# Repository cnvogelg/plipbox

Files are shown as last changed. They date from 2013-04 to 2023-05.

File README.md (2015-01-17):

plipbox
=======

plipbox is an Arduino-based device that allows to connect low-end classic
Amigas via Ethernet to your local network. It bridges IP traffic received
via PLIP on the parallel port of the Amiga to the Ethernet port attached
to the Arduino.

Copyright (C) 2012-2015 Christian Vogelgsang <chris@vogelgsang.org>

Released under the GNU Public License V2 (see COPYING for details)

Introduction
------------

With the [plip2slip][1] project I already presented a device that uses a cheap
AVR 8 bit microcontroller (as found on the popular Arduino boards) to bridge
network traffic from the Amiga's parallel port (with the [MagPLIP][2] protocoll)
to another machine via a fast serial link.

plipbox extends the plip2slip project and replaces the serial link for IP traffic
with an on-board Ethernet port. This allows you to connect your Amiga directly
to your local network without any other machine assisting.

With the on-board Ethernet port the plipbox HW is more complex than the plip2slip
HW, but I tried to use common and easy available HW modules to simplify the
recreation of this device. This allows even novice users to build their own
plipbox. (See the hardware document for details).

The firmware for plipbox is open-source and hosted on [GitHub][3].
Clone this repository if you want to build the firmware yourself or if you
want to play around with it. 

[1]: http://lallafa.de/blog/amiga-projects/plip2slip/
[2]: http://aminet.net/package/comm/net/magPLIP38.1
[3]: https://github.com/cnvogelg/plipbox

Download Releases
-----------------

See my [plipbox blog page][4] for downloads of the current release archives.
These archives contain pre-built firmware and Amiga driver binaries in addtion
to the source code here.

[4]: http://lallafa.de/blog/amiga-projects/plipbox/

Documentation
-------------

 - [Change Log](ChangeLog.md): Changes in the releases
 - [Introduction](doc/src/intro.md): Introduction on plipbox
 - [Benchmarks](doc/src/benchmark.md): Performance measurements
 - [Hardware](doc/src/hardware.md): How to build the device hardware
 - [Firmware](doc/src/firmware.md): How to setup the firmware
 - [Amiga Setup](doc/src/amiga.md): How to setup plipbox.device on your Amiga
 - [Python Emulator](doc/src/python.md): A plipbox emulator if you run your Amiga in FS-UAE

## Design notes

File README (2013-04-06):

plipbox
=======

plipbox is an Arduino-based device that allows to connect low-end classic
Amigas via Ethernet to your local network. It bridges IP traffic received
via PLIP on the parallel port of the Amiga to the Ethernet port attached
to the Arduino.

Copyright (C) 2012 Christian Vogelgsang <chris@vogelgsang.org>

Released under the GNU Public License V2 (see COPYING for details)

Introduction
------------

With the plip2slip[1] project I already presented a device that uses a cheap
AVR 8 bit microcontroller (as found on the popular Arduino boards) to bridge
network traffic from the Amiga's parallel port (with the MagPLIP[2] protocoll)
to another machine via a fast serial link.

plipbox extends the plip2slip project and replaces the serial link for IP traffic
with an on-board Ethernet port. This allows you to connect your Amiga directly
to your local network without any other machine assisting.

With the on-board Ethernet port the plipbox HW is more complex than the plip2slip
HW, but I tried to use common and easy available HW modules to simplify the
recreation of this device. This allows even novice users to build their own
plipbox. (See the hardware document for details).

The firmware for plipbox is open-source and hosted on GitHub [3].
Clone this repository if you want to build the firmware yourself or if you
want to play around with it. 

Currently, no official firmware release is available but I will post
development snapshots to the GitHub download section so you can already
play with the device.

[1] http://lallafa.de/blog/amiga-projects/plip2slip/
[2] http://aminet.net/package/comm/net/magPLIP38.1
[3] https://github.com/cnvogelg/plipbox

plipbox Documentation
---------------------

 doc/hardware.txt               How to build the device hardware
 doc/terminal.txt               How to setup a serial terminal for command mode
 doc/amiga.txt                  How to install the AMIGA network module

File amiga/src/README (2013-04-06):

the plipbox source is heavily based on the magPLIP driver found on aminet.net:

http://aminet.net/package/comm/net/magPLIP38.1

magPLIP - SANA II compliant PLIP device driver for AmiTCP/IP, Envoy,
	    AS225 and other networking packages

  (C) Copyright 1993-1994 Oliver Wagner, Michael Balzer
  (C) Copyright 1995 Jan Kratochvil & Martin Mares
  (C) Copyright 1995-1996 Marius Groeger
      All Rights Reserved.

  Changes have been made by Stéphane Zermatten to the driver to connect
  a LinuxBox to an Amiga via a LapLing cable, based on the release 37.8.

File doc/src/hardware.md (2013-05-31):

plipbox: Hardware
=================

1. Arduino (2009) and Nano
--------------------------

The firmware was implemented on a prototype build with an Arduino 2009 board
and an ATmega328 running at 16 MHz. The final (production) version of plipbox
was build with an Arduino Nano v3 board.

You can build either version but I suggest to favor the Nano version as it is
more compact. Instead of an original Arduino board you can also use one of the
many Arduino clones if the ROM size is sufficient (32K here), the AVR chip
matches and enough I/O pins are available. Also a new Arduino Uno is a working
alternative to the 2009 version .

Setting up the missing parts for your plipbox isn't that hard:
All you need is to by some extra components and wire them together.

### 1.1 Network with ENC28J60 Chip

The essential addition to your Arduino board is a network shield or network
expansion card. Please note, that you need a network card with a *ENC28J60* chip
from Microchip. Cards using a *WizNet* chip will *NOT* work! (e.g. The Arduino
Ethernet Shield)

I used the [ENC28J60 Ethernet Module][1] from iteadstudio for the Arduino 2009
prototype. The plibpox nano version uses an [Ethernet Shield for Arduino Nano
UNO][3] purchased on ebay.

*Please note*: If you use an Ethernet shield then make sure that the shield
does not require pins that are already used for the Amiga cable (see below).
E.g. the *ENC28J60 Ethernet Shield* from iteadstudio will not work as
it uses some `DIGITAL` pins for extra functions like an SD card.

The wiring of the Ethernet module is as follows:

        ENC28J60 Ethernet Module     Function           Arduino
        ------------------------     -----------------  ----------------- 
          GND                         GND               GND
          SS                          Slave Select      DIGITAL 10 (PB2)
          MOSI                        Slave In Data     DIGITAL 11 (PB3)
          MISO                        Slave Out Data    DIGITAL 12 (PB4)
          SCK                         SPI Clock         DIGITAL 13 (PB5)
          VCC                         +3.3V Supply      (see Note)
    
*Note*: The Ethernet module needs a 3.3V supply while your Arduino 2009 needs
to run on +5V. Although the Arduiono already provides a +3.3V power source on a
pin, it will be too weak to feed the Ethernet chip. I opted to use a 5V to 3.3V
regulator to supply the ethernet module. You can use a ready-made 3.3V
regulator board if you don't want to build it yourself. See for example at
[Sparkfun][2]. The plipbox nano version does need no extra power converter. It
is already shipped with the Ethener Nano shield.

[1]: www.iteadstudio.com
[2]: www.sparkfun.com
[3]: http://www.ebay.de/itm/Ethernet-Shield-for-Arduino-Nano-UNO-R3-work-as-ENC28J60-RJ45-Webserver-/170972854883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

### 1.2 Amiga Parallel Port Cable or Adapter

You need to build a cable from the Amiga Parallel Port (DB 25 male) to the
Arduino. Try to use only a short wire length otherwise signal quality will
suffer. Up to 10 cm are suitable lengths.

The plipbox nano uses a slightly different pin out compared to the original
Arduino 2009 prototype. This change was necessary as the nano shield uses
DIGITAL 2 as (unused) IRQ line from the ENC28J60 chip. Therefore the /STROBE
signal was moved to PD3 and SELECT there moved o PB1. /STROBE needs PD3 as
the firmware tracks external INTs for this signal.

       Amiga Parallel Port         Function          Arduino          Nano
       -------------------         ----------------  ---------------  ---------------
          17 ... 22                GND               GND Pin          <- same
          1                        /STROBE           DIGITAL 2 (PD2)  DIGITAL 3 (PD3)
          13                       SELECT            DIGITAL 3 (PD3)  DIGITAL 9 (PB1)
          11                       BUSY              DIGITAL 4 (PD4)  <- same
          12                       POUT              DIGITAL 5 (PD5)  <- same
          8                        DATA 6            DIGITAL 6 (PD6)  <- same
          9                        DATA 7            DIGITAL 7 (PD7)  <- same
          10                       /ACK              DIGITAL 8 (PB0)  <- same
          2 ... 7                  DATA 0 ... 5      ANALOG 0 ... 5   <- same
                                                     (PC0 ... PC5)

#### plipbox nano Adapter Board

For the plipbox nano it is advisable to build a small base circuit board with a
parallel port connector directly soldered and two pin headers for the Ethernet
Nano shield. So you can create a very compact design that fits directly in the
parallel port of your Amiga.

I already ship a schematic and layout for a single layer PCB that provides such
a base board:

  * [Schematic](/hardware/nano_adapter/nano_adapter_sch.pdf)
  * [Board Layout](/hardware/nano_adapter/nano_adapter_brd.pdf)

### 1.3 Serial Port for Terminal Access

The plipbox device can be configured and debugged via the serial console available
on all Arduino devices. Usually you don't need extra HW to access this serial 
port.

A virtual serial port is often available via the USB connection.

Alternatively, you can connect your plip box serial port directly to your Amiga 
and then use an Amiga terminal program to control the device. In this case you
need to connect the TxD, RxD and GND wires from your Arduino to a RS232 level
converter and then to your Amiga. The level converter is essential, as the Amiga
uses +/-12V signals and the Arduino 0/5V. _NEVER_ connect your Amiga directly!

2. Pollin.de AVR-NET-IO Board
-----------------------------

The german online shop [Pollin][1] offers with the [AVR Net IO][2a] a low cost
ATmega32 board (either as a kit for 20 EUR or [already assembled][2b] for
around 30 EUR) that is suitable for the plipbox project. It already contains
the ENC 28j60 ethernet controller chip and a DB 25 connector that is already
suitable to connect the Amiga. The only thing missing in this setup for plibox
is a small wire!

[1]: http://www.pollin.de
[2a]: http://www.pollin.de/shop/dt/MTQ5OTgxOTk-/Bausaetze_Module/Bausaetze/Bausatz_AVR_NET_IO.html
[2b]: http://www.pollin.de/shop/dt/NjI5OTgxOTk-/Bausaetze_Module/Bausaetze/AVR_NET_IO_Fertigmodul.html
    
### 2.1 Add Strobe Wire

You need to add a wire from Pin 1 of the DB 25 Connector (J5) to Pin 16 on the 
ATmega (IC5):

        DB25 / J5 Pin 1 <-------------> ATmega32 / Pin 16 (PD2) 

If its difficult for you to find the ATmega pin then you can also use Pin 1 of 
the EXT connector:

        DB25 / J5 Pin 1 <-------------> EXT Conenctor / Pin 1

### 2.2 Modify Power-Supply (optional!)

If you build the board yourself you might want to replace the 9V power supply
required with a 5V regulated power supply (e.g. USB charger). In this
[mikrokontroller.net Forum Thread][mod] you find a picture with the required
adjustments for this mod:

  - Remove D1, D4
  - Replace D2, D5 with a wire
  - Remove IC1 and connect pin 1 and 3 of IC1 with a wire

Then you can use a +5V regulated power supply on J1. 
Please watch the polarity now:

(-) Minus is next to the ethernet connector

[mod]: http://www.mikrocontroller.net/articles/AVR_Net-IO_Bausatz_von_Pollin

----
That's it! All you need to construct your own plipbox HW is ready!

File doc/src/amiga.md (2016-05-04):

plipbox: Amiga Driver Documentation
===================================

0. Changes
----------

* 2011-08-05  _38.1a_  plip2slip support
* 2012-06-03  _38.1b_  plipbox support
* 2013-04-06  _0.3_    introduced own plipbox.device ethernet device
* 2013-05-19  _0.3_    converted to markdown. added more stacks
* 2015-01-11  _0.6_    adapted to new file names

1. Supported Network Stacks
---------------------------

The following network stacks have been successfully tested with plipbox:

* AmiTCP 3.0b2
* Genesis (OS3.9)
* MiamiDX (from [Classic Workbench][cwb])
* [Roadshow 1.11][rs]

[rs]: http://roadshow.apc-tcp.de/index-de.php
[cwb]: http://classicwb.abime.net

2. Setup Hints
--------------

### 2.1 Common Setup

 - All network stacks expect the plipbox device driver in `devs:networks` on
   your system volume. So copy this file first before proceeding.

 - Copy `plipbox.device` from this release in the `amiga/bin` directory to your
   Amiga installation. Select the suitable m680x0 version for your hardware
   platform and copy the plipbox.device file without the `RELEASE_000` or
   `RELEASE_020` extension:

        copy plipbox.device_RELEASE_000 devs:networks/plipbox.device

### 2.2 AmiTCP with Network Boot Disk

 - For a very simple setup you can use the [Network Boot Disk for Amiga][nwbd]
   and start with this one. You have to modify the vanilla disk as it does
   not contain the plipdox drivers, yet.

#### Initial Setup

 - Insert this disk into your favorite Amiga emulator and perform the following
   steps to prepare the disk:
 - Initial boot enters setup of the disk. Follow steps to install but cancel
   the selection of a network driver as we will add the plipbox driver later.
 - Use the setup to configure your IP, netmask, gateway, and DNS server.
 - Finally reboot to finish setup.

#### Add plipbox Driver

 - Copy `plipbox.device` on the disk to `devs:networks` (see section 2.1). I
   recommend to mount a host directory as a virtual harddisk and take the
   driver from there (my disk is called `shared`)

        copy shared:plipbox.device devs:networks/
 - Edit the file `AmiTCP/db/interfaces` and add a line for the plipbox:

        echo "plipbox dev=devs:networks/plipbox.device" >> df0:AmiTCP/db/interfaces
 - Edit `df0:Prefs/Env-Archive/nbddriver` (aka `EnvARC:nbddriver`) and
   set `plipbox0` as the network device:

        echo plipbox0 > df0:Prefs/Env-Archive/nbddriver
 - In `EnvARC:sana2/` directory you can place an optional configuration file
   called `plipbox.config`. For options see the plipbox documentation.
   A sample file is available in directory `amiga/src` of this release.
   Example:

        echo "NOBURST" > df0:Prefs/Env-Archive/sana2/plipbox.config
 - Now reboot to activate changes
 - Use `ifconfig plipbox0` to check the status of your network interface.
   It should be UP and RUNNING.

[nwbd]: http://jpv.wmhost.com/NetworkBootDisk/

### 2.3 Genesis

  - Genesis is very similar to the AmiTCP setup (its more or less a UI for
    AmiTCP and uses its core for the network stuff)
  - Copy the plibpox.device to your system (see section 2.1)
  - Open the `GenesisPrefs`
  - In `Interfaces` select `New`
    - In `Interface` Tab enter:
      - Enter the interface `Name: plipbox0`
      - Enter `IP Address, Gateway, Netmask` to match your local network
    - In `SANA II` Tab enter:
      - `Specify SANA II device: devs:networks/plipbox.device`
    - Confirm interface creation with `Okay`
    - In `Resolve` Tab do not forget to name your DNS servers and set your
      domain name(s)
  - Note: `dynamic` setup does not work with plipbox. You must either use static
    or an external [DHCP client][dhcp] suitable for AmiTCP/Genesis.
  - Now you can start `Genesis` and enable your new `plipbox0` interface

[dhcp]: http://aminet.net/package/comm/tcp/dhcp_amitcp

### 2.4 MiamiDX

  - Launch `MiamiDX`
  - Select `Hardware` Tab and click `New`:
    - In `Select Hardware Type` pick `Ethernet`
    - Enter a name for the hardware, e.g. `Name: plipbox`
    - Keep `Type: SANA II`
    - Pick plipbox.device: `Driver: devs:networks/plipbox.device`
    - Confirm with `Ok`
  - Select `Interfaces` Tab and click `New`:
    - Pick `Interface Type: Ethernet`
    - Pick `Interface connection: LAN`
    - Select your hardware: `plipbox`
    - You can either configure your Amiga statically or with DHCP: Select
    `static` or `dynamic` in `IP Type, Netmask Type, Gateway Type`. Enter
    your network parameters in static mode.
    - Note: multicast is not supported in plipbox. Therefore, keep
    `Multicast: disabled`.
    - Note: Configure DHCP in `TCP/IP Settings...` to fetch DNS servers, too.
  - In `Databases` Tab select Table `DNS servers` and add your static DNS
  server IPs (if you don't use dynamic DNS via DHCP)
  - Do not forget to save your settings with Amiga+S or `Menu: Settings -> Save`
  - Now you can go online with your new interface `plipbox`
  - If you use multiple plipbox devices in a single network then you have to
  set a unique MAC address for each one. Select `Hardware Tab` and double
  click your `plipbox` entry. Now select `SANA-II Parameters` and enter a
  new MAC address in the `Hardware address` field.

### 2.5 Roadshow

  - Begin with copying the plipbox device driver (see section 2.1)
  - Then you need an interface configuration file for the plipbox device.
  Simply copy a template from `Storage/NetInterface` and modify this one:

        copy sys:Storage/NetInterfaces/cnet devs:NetInterfaces/plipbox

  - Now adjust the following values in the file (use either static or DHCP section!):

        device=plipbox.device
        # -- DHCP --
        configure=dhcp
        # -- static --
        address=<your ip>
        netmask=<your mask>

  - Have a look in `devs:internet/name_resolution` to set your DNS servers and
  your domain name.
  - After a reboot the interface will be brought up automatically in the
  `User-Startup` section of Roadshow
  - For testing you can activate/de-activate the interface with:

        > addnetinterface devs:netinterfaces/plipbox
        > ... use network ...
        > netshutdown

  - To make sure that the plipbox device goes offline if you shut down the net
  you have to add the following options to your interface configuration file:

        downgoesoffline=yes

  - If you use multiple plipbox devices in a single network then you have to
  assign them unique MAC addresses. You can set the MAC address of your plipbox
  with the following option in your Roadshow device configuration file:

        hardwareaddress=1a:11:a1:a0:00:01

  - A complete device config looks like:

        device=plipbox.device
        configure=dhcp
        downgoesoffline=yes
        hardwareaddress=1a:11:a1:a0:00:01

3. plipbox.device Configuration
-------------------------------

While the plipbox.device is in general zero-config and needs no adjustement,
you can control some options via a configuration file.

The text file needs to be called:

        ENV:SANA2/plipbox.config

Store your file in the environment archive to have it available after the
next reboot, too:

        ENVARC:SANA2/plipbox.config

The following options are supported:

  - **NOBURST** (switch /S) (default: burst on)
    - Starting with version 0.6 a fast burst mode is used for parallel port
      data transfer. It is always recommended to use this mode. However, if
      you experience problems with fast transfers then you can use this
      option to fall back to the old transfer protocol. Its slower but
      more reliable.

  - **TIMEOUT** (numerical key /K/N) (default: 500 * 1000) (unit: microseconds)
    - The parallel transfer uses time outs to detect error conditions.
    - Use this value to adjust timing.

  - **NOSPECIALSTATS** (switch /S) (default: special stats on)
    - The SANA-II device tracks statistics information.
    - Use this switch to disable the extra statistics information that is
      recorded during normal operation of the device.

  - **PRIORITY** (numerical key /K/N) (default: 0) (unit: AmigaOS task prio)
    - A server task is used in the plipbox.device to handle the parallel port
      transfers.
    - Use this value to alter the scheduling priority of the send/receive
      task.

  - **BPS** (numerical key /K/N) (default: 60 * 1024 * 8) (unit: bits/second)
    - A SANA-II device reports a bitrate per second value as an indication
      for the achievable transfer speed of the network device.
    - Use this parameter to adjust the speed that is reported to the TCP/IP
      stack from the device.

  - **MTU** (numerical key /K/N) (default: 1500) (unit: bytes)
    - The maximum transfer unit is the maximum number of bytes a device can
      transfer in a single packet. By default its 1500 and exactly matches
      the MTU that Ethernet uses.
    - For the plipbox the MTU size is also the size of the parallel transfers.
    - Use this parameter to set a smaller MTU and tune the transfer rates.
    - Note that a non 1500 MTU will cause fragmentation on upper levels.

4. Build plipbox.device from Source
-----------------------------------

 - Only for advanced users! All others can use the supplied binaries!
   You really need to recompile the binaries only if you want to modify
   or enhance them.
 - I cross-compile the binaries here with vamos running the SAS C V6.58 compiler
 - Install [vamos][v] on your Mac or PC
 - Copy the following Amiga Directories either from a real machine or an emulator
   to a directory on your Mac. The directory is named `$HOME/amiga/shared`
   here but you can use another directory as well but need to adjust `AMIGA_DIR`
   in `amiga/src/makefile`!

        ~/amiga/shared:
          wb310             system root of a Workbench 3.1 HD Installation
          sc                complete installation directory of SAS C 6.58
          AmiTCP-SDK-4.3    AmiTCP SDK

   The [AmiTCP-SDK-4.3][sdk] is available on Aminet
 - Enter directory `amiga/src` of this release
 - Build on your Mac or PC shell with:

        > make dist       build release files
        > make all        build without optimization
        > make opt        build with optimization
        > make clean      remove files of current build
        > make clean_dist remove all build files

 - The resulting files can then be found in `amiga/bin`

[v]: http://lallafa.de/blog/amiga-projects/amitools/vamos/
[sdk]: http://aminet.net/package/comm/tcp/AmiTCP-SDK-4.3

EOF

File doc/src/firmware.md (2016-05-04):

plipbox: Firmware Documentation
===============================

1. Flash Firmware
-----------------

Depending on your AVR hardware and the bootloader it contains when shipped you
can either use the bootloader to flash the device (e.g. via serial) or you
have to use an AVR in-system-programmer (ISP) to flash the device without
running the bootloader.

Serial flashing is described in section 1.1 and 1.2 while ISP flashing is
found in section 1.3

Here is a quick overview of devices and their required flash methods:

  * Pollin.de AVR-NET-IO: needs ISP
  * Custom ATmega 328 boards: needs ISP
  * Arduino 2009 or Arduino Nano: has Bootloader with Serial Flash Support

### 1.1 Find plipbox Serial Port

You can connect your plipbox typically via the USB port to your Mac or PC
and this will install a "virtual" serial port. Other plipbox devices have the
serial port available on 2 pins with +5V signals. Then you need an external
USB-to-Serial device to convert the serial signals to a virtual serial device.

The virtual serial port is called differently depending on your OS:

 * Macs: `/dev/cu.usbserial-<serial>`
 * Linux: `/dev/ttyUSB<num>`
 * Windows: `COM1 ... COMx`

You can find out the port associated with your plipbox by looking at the
registered devices before and after attaching the device.

### 1.2 Flashing with Serial Link

Some AVR devices like the Arduino-based ones allow you to flash the firmware
via the (virtual) serial link.

First select correct firmware file for flashing. The firmware used for the
Arduino 2009 prototype is called `*-ardiuno-*.hex` and the firmware for the
plipbox nano production version is called `*-nano-*.hex`. Choose the version
matching your hardware. Both have the same features but use a slightly
different pinout for accessing the Amiga's parallel port.

For flashing the firmware you need a flash tool on your Mac/PC that talks via
this serial port. I use [avrdude][ad] here. It is available on all platforms and
a command line tools.

[ad]: http://www.nongnu.org/avrdude/

Now open a shell/terminal/cmd.exe on your OS and call the firmware tool with:

        > avrdude -p m328p -P <your_serial_port> -b 57600 -c arduino -U flash:w:plipbox-0.x-57600-arduino-atmega328.hex

This assumes that you have the plipbox firmware file called
`plipbox-0.x-57600-arduino-atmega328.hex` in your current directory.
In the release archive you can find it in the `avr/firmware` directory.

Furthermore, replace `<your_serial_port>` with the device name of your
Ardiuno serial device found in section 1.1.

If everything works well then you will see the following output:

        avrdude: AVR device initialized and ready to accept instructions

        Reading | ################################################## | 100% 0.00s

        avrdude: Device signature = 0x1e950f
        avrdude: NOTE: FLASH memory has been specified, an erase cycle will be performed
                 To disable this feature, specify the -D option.
        avrdude: erasing chip
        avrdude: reading input file "plipbox-0.x-57600-arduino-atmega328.hex"
        avrdude: input file plipbox-0.x-57600-arduino-atmega328.hex auto detected as Intel Hex
        avrdude: writing flash (16596 bytes):

        Writing | ################################################## | 100% 4.67s

        avrdude: 16596 bytes of flash written
        avrdude: verifying flash memory against plipbox-0.x-57600-arduino-atmega328.hex:
        avrdude: load data flash data from input file plipbox-0.x-57600-arduino-atmega328.hex:
        avrdude: input file plipbox-0.x-57600-arduino-atmega328.hex auto detected as Intel Hex
        avrdude: input file plipbox-0.x-57600-arduino-atmega328.hex contains 16596 bytes
        avrdude: reading on-chip flash data:

        Reading | ################################################## | 100% 3.37s

        avrdude: verifying ...
        avrdude: 16596 bytes of flash verified

        avrdude: safemode: Fuses OK

        avrdude done.  Thank you.

Now your device is fully operational and we use the serial link to communicate
with plipbox.

### 1.3 Flashing with ISP

All AVR boards can be flashed with an In-System-Programmer (ISP) device. This
device directly programs the flash ROM. The ISP is an external tool that
is also typically connected via USB to your PC. I use the [USBasp][ua] thats
a cheap AVR ISP that is supported by avrdude and has a USB connector. You can
build one yourself or buy a [kit][uk]. You also find these devices on ebay
and amazon.

The AVR-NET-IO-Board from Pollin.de needs to be flashed via ISP and this
firmware variant:

        plipbox-<version>-57600-avrnetio-atmega32.hex

Again you can use `avrdude` to flash the firmware. The command avrdude is as
follows:

        > avrdude -p m32 -c usbasp -U flash:w:plipbox-0.1-57600-avrnetio-atmega32.hex

Please note the different flash adapter `usbasp` here and that you do not need
a serial speed now.

[ua]: http://www.fischl.de/usbasp/
[uk]: http://www.fundf.net/usbasp/

2. plipbox Configuration
------------------------

The plipbox firmware uses the serial link available on your plipbox to show you
device information and allows you to configure the device in this terminal.

Starting with version 0.3 the plipbox device is essentially a zero-config device,
i.e. you don't have to alter any parameters for typical default operation.

Nevertheless, the firmware offers options to fine tune its behaviour and provides
commands for statistics and diagnosis.

### 2.1 Setup your terminal program

On your Mac/PC you will need a terminal program to talk via the serial link.
If you haven't got a favorite one then have a look at [CoolTerm][ct] for Mac OSX
or [TeraTerm][tt] for Windows. Linux users might try [minicom][mc] or [picocom][pc].

[ct]: http://freeware.the-meiers.org/
[tt]: http://www.ayera.com/teraterm/
[mc]: http://alioth.debian.org/projects/minicom/
[pc]: http://code.google.com/p/picocom/

Run your terminal program and select the serial port of your plipbox (see
section 1.1). For the serial port select the following parameters:

  * 8 N 1 = 8 data bits, no parity, 1 stop bit
  * no hardware (RTS/CTS) hand shaking
  * no software (XON/XOFF) hand shaking

### 2.2 Entering/Leaving Command Mode

If everything went well you will see the startup message of the plipbox
firmware after a reset of the device:

        Welcome to plipbox <version> <date>
        by lallafa (http://www.lallafa.de/blog)

You see all important parameters of your device and their current values.
Below is the current status of the device starting with `eth rev` that
tells you that the firmware correctly detected your Ethernet chip.

If you press **Return** in your terminal program then the device will enter
*command mode*. This mode allows you to enter commands that the device
will execute. Its mainly used to set parameters and load/save them.

While the device is in command mode it does not handle any transfers - its
completely inactive. You have to quit command mode first to return to normal
operation.

Command mode is shown with a command prompt "> " in the beginning of a line.

If you enter **q** and **Return** you give the *quit* command to leave the
command mode and the device returns to active mode.

If you enter **?** and **Return** a help text will be displayed. It shows
you all the commands that are available.

While running in active mode you can also press keys to trigger commands.
See section 2.4 for details on those keyboard commands.

### 2.3 plipbox Commands

See this section for a complete list of all commands available.

A command usually consists of a command name and optional arguments. All
are seperated by spaces on the command line. The arguments are always numbers
and given in hexadecimal (only IP address is given in decimal). The numbers
have a fixed size of either 2 or 4 digits and are denoted as follows:

  - **nn**: byte (8 bit)
    - hex value
    - always give 2 digits.
    - Example: `af`, `00`
  - **nnnn**: word (16 bit)
    - hex value
    - always give 4 digits.
    - Example: `0010`, `ab12`
  - **nn:nn:nn:nn:nn:nn**
    - 6 bytes in hex values.
    - Example: `1a:11:af:a0:47:11`
  - **nnn.nnn.nnn.nnn**
    - 4 bytes given in decimal. always give 3 digits per byte.
    - Example: `192.168.0.42`

A command is always finished by pressing **Return**.

#### 2.3.1 Common Commands

  - **q**: Leave command mode
  - **r**: Soft reset device and restart it
  - **v**: Show plipbox firmware version

#### 2.3.2 Parameter Storage

  - **p**: Show parameters
  - **ps**: Save parameters to EEPROM
  - **pl**: Load parameters from EEPROM
  - **pr**: Reset parameters to factory defaults

#### 2.3.3 Configuration Commands

  - **m nn:nn:nn:nn:nn:nn:nn** (Mac Address)
    - Set the mac address of the plipbox device.
    - Always ensure that the firmware uses the same value as the
      plipbox.device driver!
    - Normally you don't need to alter the mac address via this parameter.
      The driver will automatically push the mac address to the firmware on
      every change.

  - **fd [nn]** (Full Duplex)
    - Toggle between Ethernet full and half duplex mode. If fd is
      set to one then full duplex mode is enabled. Note: the duplex mode can
      only be switched after a reset of the device. So set your desired value
      with this command then save the parameters with **ps** and reset the
      device with **r** to test the new setup.

  - **fc [nn]** (Flow Control)
    - Toggle the use of Ethernet flow control to limit the rate
      of incoming Ethernet packets. If the parameter is set to one then flow
      control is enabled.

#### 2.3.4 Statistics Commands

  - **sd** (Dump Statistics)
    - Dump the statistics information. The plipbox records a number of
      typical network statistics including sent packets, send bytes, transfer
      errors and so on for each direction. This command prints the currently
      accumulated values.

  - **sr** (Reset Statistics)
    - Reset the statistics counters.

#### 2.3.5 Test Commands

plipbox offers a rich set of diagnosis (or test) modes. Some of them use extra
parameters that can be configured in command mode. See section 3 for details.

  - **tl nnnn** (Test Packet Length) (4 byte hex word)
    - The number of bytes that will be transferred per packet in test mode.

  - **tt nnnn** (Test Packet Ethernet Type) (4 byte hex word)
    - The ethernet type of the packets that will be sent in test mode.

  - **ti nnn.nnn.nnn.nnn** (Test Mode IP) (IP address)
    - In PIO test mode the plipbox device has its own IP address

  - **tp nnnn** (Test Mode UDP Port) (4 byte hex word)
    - In PIO test mode the plipbox answers UDP requests on this port

  - **tm [nn]** (Toggle test submode)
    - Some test modes have a sub mode. Use this command to toggle it.

### 2.4 plipbox Key Commands

If you are in *active mode* (not command mode) then you can press some command
keys to trigger actions on the device:

#### 2.4.1 Mode Selection

  - **1** (Enter Bridge Mode)
  - **2** (Enter Bridge Test Mode)
  - **3** (Enter PIO Test Mode)
  - **4** (Enter plipbox Protocol Test Mode)

#### 2.4.2 Statistics

  - **s** (Dump Statistics)
    - Dump the current statistics.
    - Similar to **sd** command.
  - **S** (Reset Statistics)
    - Reset statistics counters.
    - Similar to **sr** command.

#### 2.4.3 Diagnosis

  - **v** (Toggle Verbose)
    - If verbose is enabled then detailed information on every transfer
      is printed
    - Please note that verbose significantly degrades the performance of
      the device and should only be used for analysis purposes.
  - **p** (Send a Packet)
  - **P** (Send a Packet silent)
    - Trigger sending a test packet
    - Works in plipbox test mode only
  - **a** (Toggle auto-send Packets)
    - If enabled it will automatically send packets continuously until
      you stop auto mode again.

## 3. plipbox Run Modes

### 3.1 Terms

The plipbox device consists of two sub parts:

  - The **parallel port** connects to the Amiga. There the plipbox
    protocol (short: pb) is talked to transfer packets from/to the Amiga
    on this interface.
  - The **PIO port** (PIO stands for packet I/O). Currently, an ethernet
    controller is the PIO device of the plipbox. The PIO port transfers
    the packets to your local network.

Overview:

        | Local Network        +------- plipbox -----+
        |                +------------+    +------------------+
        |<-------------->| PIO Port   |    | PB/Parallel Port |<------> Amiga
        |                +------------+    +------------------+
        |                      +---------------------+

### 3.2 Normal Operation: Bridge Mode

After startup plipbox enters **bridge mode**. This is the normal operation mode
of the device: Both PIO and parallel port are active and packets are received
on both ports. If a packet arrives then the packet is sent on the other port.

On your Amiga you use the `plipbox.device` and your TCP/IP stack (e.g.
`Roadshow`) to transfer your internet traffic.

Incoming PIO Traffic:

        | Local Network
        |                 +-----------+
        |---- Packets --->|  plipbox  |---- Packets ---> Amiga
        |                 +-----------+                  TCP/IP Stack
        |                PIO         PB                  + plipbox.device

Incoming PB Traffic:

        | Local Network
        |                 +-----------+
        |<--- Packets ----|  plipbox  |<--- Packets ---- Amiga
        |                 +-----------+                  TCP/IP Stack
        |                PIO         PB                  + plipbox.device

Use command key **1** (see section 2.4.1) to enable this mode.

### 3.3 UDP Roundtrip Tests

These tests allow you to test sending traffic across plipbox with a special
test setup: A PC test program called **pio_test** (see `python` directory of
the software distribution) is used to generate special UDP packets that are
sent to the plipbox. The plipbox will bridge them to the Amiga and a special
test program there will return them. The returned packets are bridged back to
the PIO port and sent back to the PC. The PC test program will then send the
next UDP packet on the next round trip. After a given number of packets the
test program stops and gives you average transfer speeds.

If something went wrong then a packet sent will not arrive in time at the
pio_test program and the test will be aborted with an error.

#### 3.3.1 Loopback with TCP/IP Stack: Bridge Mode + udp_test

The basic operation in this test mode is to use the TCP/IP Stack on the Amiga
to receive and reply the packets. The plipbox device is operated in the normal
Bridge Mode. So this setup tests all components and plipbox is run in normal
bridge mode.

UDP Packet Round Trip of Test:

      +-----------+ 1. Send UDP Pkt +---------+ 2. Bridge       +--------------+
      | PC with   |---------------->|         |---------------->| Amiga        |
      |           |                 | plipbox |                 | TCP/IP Stack |
      | pio_test  | 4. Bridge       |         | 3. Reply UDP    | pb.device    |
      | running   |<----------------|  Bridge |<----------------| +udp_test    |
      +-----------+                 +---------+                 +--------------+

Tested Components:

- local network (link PC <-> plipbox)
- plipbox Bridge Mode
- plipbox.device in normal operation
- TCP/IP Stack on Amiga

Test Setup:

- On plipbox:
    - Make sure mode is Bridge (key **1**)
- On Amiga:
    - Configure your TCP/IP with plipbox.device for normal operation
    - Bring up the plipbox network interface and retrieve assigned IP: `AmigaIP`, e.g. 192.168.2.42
- On PC:
    - Make sure you can reach the Amiga by pinging the AmigaIP

            > ping 192.168.2.42

    - Now launch the test program and give the Amiga's IP

            > python27 pio_test -a 192.168.2.42 -c 1000

    - Note: The `-c` option gives the number of test packets to be sent

#### 3.3.2 Loopback with SANA-II Device Interface

This test omits the TCP/IP stack running on the Amiga. The SANA-II device
driver is still in the loop and launched by a special test program called
**dev_test** from this release.

With the missing stack the Amiga is not able to perform networking including
ARP and UDP handling. The **Bridge Test** mode of the firmware handles ARP und
UDP now on its own and only passes the packets to the Amiga for performance
evaluation.

All test packets are still transferred across the SANA-II interface of
plipbox.device to the dev_test program.

UDP Packet Round Trip of Test:

      +-----------+ 1. Send UDP Pkt +---------+ 2. Bridge       +--------------+
      | PC with   |---------------->|         |---------------->| Amiga        |
      |           |                 | plipbox |                 |              |
      | pio_test  | 4. Bridge       |  Bridge | 3. Reply UDP    | pb.device    |
      | running   |<----------------|  Test   |<----------------| +dev_test    |
      +-----------+                 +---------+                 +--------------+

Tested Components:

- local network (link PC <-> plipbox)
- plipbox Bridge Mode
- plipbox.device in normal operation
- SANA-II API

Test Setup:

- On plipbox:
    - Enter bridge test mode (key **2**)
    - In Parameters set:
        - IP address and UDP port (`ti`, `tp`)
        - Test mode ist set to **1** (`tm`)
- On Amiga:
    - Stop your TCP/IP Stack if its still running.
    - Run **dev_test** with **-d plipbox.device**
- On PC:
    - Make sure you can reach the plipbox by its address

    > ping 192.168.2.42

    - Now launch the test program and give the plipbox's IP

    > python27 pio_test -a 192.168.2.42 -c 1000

    - Note: The `-c` option gives the number of test packets to be sent

#### 3.3.3 Internal Loopback in plipbox.device

This test mode removes the SANA-II interface API from the packet roundtrip. The
packets are still sent from the plipbox to the Amiga but now the plipbox.device
returns them internally.

UDP Packet Round Trip of Test:

      +-----------+ 1. Send UDP Pkt +---------+ 2. Bridge       +--------------+
      | PC with   |---------------->|         |---------------->| Amiga        |
      |           |                 | plipbox |                 |              |
      | pio_test  | 4. Bridge       |  Bridge | 3. Reply UDP    | pb.device    |
      | running   |<----------------|  Test   |<----------------|              |
      +-----------+                 +---------+                 +--------------+

Tested Components:

- local network (link PC <-> plipbox)
- plipbox Bridge Mode
- plipbox.device internal loopback

Test Setup:

- On plipbox:
    - Enter bridge test mode (key **2**)
    - In Parameters set:
        - IP address and UDP port (`ti`, `tp`)
        - Test mode ist set to **0** (`tm`)
- On Amiga:
    - Stop your TCP/IP Stack if its still running.
    - Run **dev_test** with **-d plipbox.device**
- On PC:
    - Make sure you can reach the plipbox by pinging its address:

    > ping 192.168.2.42

    - Now launch the test program and give the plipbox's IP

    > python27 pio_test -a 192.168.2.42 -c 1000

    - Note: The `-c` option gives the number of test packets to be sent

### 3.4 PIO Test Mode

The PIO Test Mode is an isolated transfer test for the PIO port of the plipbox.
No parallel transmission to the Amiga is involved. Only the raw transfer speed
of the PIO device (here the Ethernet) is measured.

Tested Components:

- local network (link PC <-> plipbox)
- PIO device (Ethernet port) of plipbox

Test Setup:

- On plipbox:
    - Enter PIO test mode (key **3**)
    - In Parameters set:
        - IP address and UDP port (`ti`, `tp`)
        - Test mode ist set to **0** (`tm`)
- On PC:
    - Launch the test program and give the plipbox's IP

    > python27 pio_test -a 192.168.2.42 -c 1000

    - Note: The `-c` option gives the number of test packets to be sent

### 3.5 PB Test Mode

This test mode only transfers packets between the plipbox and the Amiga. The
packet transfer is initiated by the plipbox and then retrieved and replied with
plipbox.device's internal loopback.

You need to open the plipbox.device and set it to online with a tool like
[sanautil][su] or dev_test from this release.

This mode is suitable to estimate the raw transfer speed of packet sent across
the parallel port and measures the performance of the current plipbox protocol
implementation.

Tested Components:

- plipbox protocol
- parallel port transfer speed

Test Setup:

- On Amiga:
    - Stop your TCP/IP Stsck if its still running
    - Run **dev_test -d plipbox.device** or
    - Run **sanautil -d plipbox.device online**
    - Stop with **Ctrl-C**
- On plipbox
    - Enter PB Test Mode (key **4**)
    - On serial prompt:
        - Send a single test packet (key **p** or **P**)
        - Start auto test:
            - Press key **a** to begin test
            - Press key **s** to see current statistics
            - Press key **a** again to stop test
            - Press key **s** for final stats or **S** to reset stats

[su]: http://aminet.net/package/comm/net/sanautil

### 3.6 PC Test Tools

The tools are found in the **python** sub directory of the release and you need
Python 2.7 on your system to run it.

#### pio_test

This tool is used to send UDP packets to the plipbox and measures the round
trip, i.e. the time until the packet is returned from plipbox.

        usage: pio_test [-h] [-v] [-a ADDRESS] [-p TGT_PORT] [-P SRC_PORT]
                        [-s DATA_SIZE] [-c COUNT] [-d DELAY]

        optional arguments:
          -h, --help            show this help message and exit
          -v, --verbose         be verbose
          -a ADDRESS, --address ADDRESS
                                IP address of plipbox
          -p TGT_PORT, --tgt-port TGT_PORT
                                UDP port of plipbox
          -P SRC_PORT, --src-port SRC_PORT
                                UDP port here
          -s DATA_SIZE, --data-size DATA_SIZE
                                size of test data
          -c COUNT, --count COUNT
                                number of packets
          -d DELAY, --delay DELAY
                                delay in ms

### 3.7 Amiga Test Tools

The tools are found in **amiga/bin** sub directory and compiled for different
m68k CPU variants. Like with `plipbox.device` pick the one matching your Amiga.

#### dev_test

This little tool opens the given SANA-II device and waits for any incoming packets.
All received packets are simply bounced and sent back with almost no modification:
Only source and target address and UDP port are swapped.

        dev_test -D=DEVICE/K,-U=UNIT/N/K,-M=MTU/N/K,-V=VERBOSE/S

        -D=DEVICE       SANA-II device file to be used (default: plipbox.device)
        -U=UNIT         Unit of device that will be opened (default: 0)
        -M=MTU          Maximum size of packets to be received
        -V=VERBOSE      Be more verbose

Never run this tool if your Amiga TCP/IP stack is running.

#### udp_test

This tool uses `bsdsocket.library` of your Amiga's TCP/IP stack to open a UDP socket
on the given port. Any packet that arrives on this port is simply bounced and sent
back to the sender.

        udp_test -V=VERBOSE/S,-P=PORT/K/N

        -P=PORT         UDP Port to be opened (default: 6800)
        -V=VERBOSE      Be more verbose

EOF

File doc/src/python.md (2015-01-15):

plipbox: Python Emulator
========================

1. Introduction
---------------

Recently, I had some time to spend and wanted to work on the [plipbox][pb]
project's Amiga driver. Unfortunately, I only had my MacBook Pro with me and no
Amiga or plipbox hardware.

What does a SW developer do if the real hardware is not at hand?

Yes, you write an emulator that represents the missing HW in SW on a machine
you have access to...

### Adding a Virtual Parallel Port Protocol in FS-UAE

That said, I installed all required Amiga SW in a virtual environment in
[FS-UAE][fs] on my Mac and soon I had my **plipbox.device** SANA II driver
talking with the virtual parallel port in FS-UAE. What was missing now is a
protocol that communicates the complete I/O state from FS-UAE to another
process. Then I could write a standalone application that does emulate the
plipbox firmware and plipbox.device in FS-UAE would be operational.

I defined a simple two-byte bi-directional protocol called [**vpar**][vp] that
communicates any change in the emulation of FS-UAE's Amiga parallel port to an
external process and also receives external changes for input lines from the
process and realizes them in FS-UAE's emulated parallel port.

Having a POSIX compatible system with pseudo-terminals (ptys) I devised the
link between both processes as a simple file-open interface in FS-UAE and a pty
in the plipbox emulator (Note: any other interprocess mechanism works here also
but this one was very easy to add in FS-UAE).

The setup looks like this:

        +----------+                                  +---------+
        | plipbox  |                                  | patched |
        | emulator |--(opens)--> [PTY] <--(file I/O)--| FS-UAE  |
        +----------+                                  +---------+
                    <--------- vpar protocol -------->

All required changes to FS-UAE are available in my clone of the FS-UAE
repository on [GitHub][gh] in the `chris-devel` branch.

For the plipbox emulator application I chose my favorite script language
Python. With it setting up the pty for inter-process communication and
implementing the vpar protocol peer was done in a few hours.

[pb]: http://lallafa.de/blog/amiga-projects/plipbox
[fs]: http://fs-uae.net
[vp]: https://github.com/cnvogelg/fs-uae-gles/blob/chris-devel/vpar.md
[gh]: https://github.com/cnvogelg/fs-uae-gles/tree/chris-devel

### Setting up the Network

Ok, the plipbox emulator in Python can now talk PLIP via vpar's virtual
parallel port. The next step is to add access to an Ethernet device on the
lowest frame level for our plipbox emulator.

I had a look at the [pcap][pc] library that allows injecting packets into
an existing adapter, but the Python bindings often lacked the inject feature
of the library and so I dropped this idea.

Then I found a setup using a [TAP][tt] device to easily create and receive
ethernet packets from a user space application. Combine this with a real
ethernet adapter via an interface bridge and you have access to real ethernet
with a simple TAP file I/O interface (opening `/dev/tap0`) from your
application.

The setup looks like this:

        +----------+              +---------+                +----------+
        | Real Eth |              | TAP     |                | plipbox  |
        | Adapter  |<-- Bridge -->| Adapter |<-- File I/O -->| emulator |
        +----------+              +---------+                +----------+
            en1         bridge0       tap0
            +----- OS net interfaces ----+

For the real ethernet adapter I use a second USB ethernet adapter on my Mac
that is not configured (IP: 0.0.0.0) but active (up) in Mac OS X. This way OS X
does not use it and my emulator can use it exclusively.

Creating the TAP device and building the bridge with the real adapter is done
with some sudo'ed system command right in the startup of the emulator.

Note: the TAP driver is not shipped with Mac OS X itself, but you can add it by
installing the ones from the [TUN TAP OSX][to] project.

[pc]: http://www.tcpdump.org  
[tt]: http://en.wikipedia.org/wiki/TUN/TAP
[to]: http://tuntaposx.sourceforge.net

### Putting it all together

On top of the vpar Python module I implemented the magPLIP protocol layer in
an own Python class. Now all pieces to create the plipbox were available.

The plipbox main script sets up the vpar, magplip, and ethernet with TAP and
interface bridge. In the main loop it does I/O multi-plexing with select() on
the file descriptor for the vpar PTY and for the TAP file. 

A packet arriving from TAP is filtered (i.e. multicast and unknown broadcasts
are removed) similar to the real plipbox firmware and then delivered to the
emulated Amiga via the vpar connection.

A packet incoming via PLIP is directly delivered to the local network and thus
written to the TAP file.

That's it! A working plipbox running as a Python script on my Mac... 
Similar to the firmware I added some optional debugging output to see the
packet contents and to measure the timing and latency.

2. Setup
--------

If you want to setup your own plipbox emulation you'll need the following
prerequisites. Please note that the current approach relies on PTYs, TAP and
bridge network devices and thus requires an OS supporting these cool things.
I currently tested only Mac OS X and Linux. 

### Common Setup

- On all platforms you'll need a Python 2.7 without any special packages
  installed

### Mac OS X Installation

- First install the [TUN TAP OS X driver][tt] 

- The new TAP device files need special access rights to use them. I added my
  user to group `wheel` to gain access to these files:

        # dscl . -append /groups/wheel GroupMembership $LOGNAME

- plipbox sets up the interface bridge with some ifconfig commands that require
  root privileges. The script calls **sudo** to perform these actions. You can
  adjust your `/etc/sudoers` file with `visudo` to gain access without entering
  a password each time:

        %admin  ALL=(ALL) NOPASSWD: ALL

- Make sure that the ethernet interface you want to bridge is not configured
  for IP (IPv4 address is 0.0.0.0) but enbaled (i.e. up)

[tt]: http://en.wikipedia.org/wiki/TUN/TAP

### Linux Installation

- similar to OSX setup **sudo** to call commands without password

- the Linux kernel needs TUN/TAP support with the `tun` kernel module. Modern
  Linux systems ship this module already. If this module is not installed you
  can install it with `insmod tun`. Just make sure to find the device node
  `/dev/net/tun` in your file system.

- you need the `tunctl` tool. On Debian/Ubuntu systems it is available in the
  `uml-utilities` package.
  
- you need the `brctl` ethernet bridge tool. On Debian/Ubuntu systems it is
  available in the `bridge-utils` package.

3. Usage
--------

### Running plipbox

You typically run the plipbox emulator with:

      > cd python
      > ./plipbox -e <ethernet_if>

The `-e` option is required to set the ethernet device you want to use for
bridging. On Mac OS X this interface is typically named `en*`, on Linux it is
`eth*`.

You can quit plipbox by pressing `CTRL+C`. This will shut down all resources
including TAP and bridge interface and removes the vpar PTY.

### Running FS-UAE with vpar support

When the plipbox emulator is started it will wait for the connect from FS-UAE.
So start this tool next. Make sure to use my patched 
[FS-UAE with vpar support][gh]. In your FS-UAE configuration add the following 
line to enable vpar support:

      parallel_port = raw:/tmp/vpar

The path `/tmp/vpar` is the default link path that will be created by plipbox
and points to the PTY that was opened by plipbox for vpar communication. You
can change this path with the `-l` option.

You can set the environment variable `VPAR_DEBUG=1` before running FS-UAE to
see low-level vpar debug information similar to the `-d` debug switch in the
plipbox emulator.

If you quit FS-UAE then plipbox will be notified and shut down, too.

[gh]: https://github.com/cnvogelg/fs-uae-gles/tree/chris-devel

### Plipbox options

The following **plipbox options** are available:

- **-v**: enable verbose output. Shows incoming and outgoing packets.
- **-d**: enable debug output. Show the vpar and magplip diagnose messages.
  This allows you to diagnose the low level parallel protocol.
- **-e <ifname>**: Name of ethernet device to be used for bridging.
- **-t <ifname>**: Name of TAP device that will be created for packet generation
  from virtual PLIP. 
- **-l <path>**: The link that will point to the PTY that FS-UAE with vpar
  support can connect to. 
- **-E**: disable filtering of packets arriving from Ethernet
  
EOF

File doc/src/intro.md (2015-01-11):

plipbox: Introduction
=====================

This document gives a technical introduction on how the plipbox device operates.

The plipbox device firmware implements a bridge for network packets arriving
on the parallel port of the Amiga (called PLIP) and the local Ethernet connected
to the plipbox hardware.

1. NAT device
-------------

Version 0.1 and 0.2 of plipbox implemented a NAT device between the parallel
PLIP interface and the Ethernet adapter.

A NAT device connects two distinct IP networks, i.e. both the PLIP and Ethernet
side of the plipbox have different IP networks and thus the plipbox has to 
have two addresses (one for each sub net):

                             +-----plipbox-----+
                             |          1a:11:a1:a0:47:11        
        +-------+   IP  +-----------+     +----------+ ARP/IP
        | Amiga | <---> | PLIP Port |-NAT-| Eth Port | <---> Local Network
        +-------+  p2p  +-----------+     +----------+  lan
       192.168.0.1      192.168.0.2      192.168.2.133        192.168.2.x
      magplip.device         |                 |        mask: 255.255.255.0
                             +-----plipbox-----+          gw: 192.168.2.1

In this setup you have to configure quite a lot: You have to set your Amiga IP
and the PLIP port IP in an own sub net. Additionally, you have to set your
Ethernet port IP to an address suitable for your local network. If you have a
DHCP server in your local network then the plipbox firmware can use this
protocol to automatically acquire the Ethernet port IP address and sub net mask.

On the Amiga side you have to select a point-to-point networking setup in your
TCP/IP software stack. This defines one address for the magPLIP interface
(here 192.168.0.1) and one for the PLIP Port in plipbox (here 192.168.0.2).
All packets sent from the Amiga will arrive at the gateway on the PLIP Port.

Now NAT takes place and the sender addresses are replaced in all IP packets
before sending them to the Ethernet: A packet originating from the Amiga
(192.168.0.1) is sent with the Eth Port as sender (192.168.2.133) to the
local network.

If a reply IP packet arrives at the plipbox's Eth Port then NAT is reversed
and replaces the destination address of the Eth Port (192.168.2.133) with
the one of the Amiga (192.168.0.1). Then the packet is sent via PLIP to the
Amiga.

Note that in contrast to other NAT devices here no port remapping is done:
We NAT only a single machine (the Amiga) and we don't use our own ports locally.
This simplifies NATting a bit as not port maps need to be managed.

On the point-to-point link only IP packets are transported. All other types
especially ARP packets make no sense here as a HW address to IP mapping is not
required here. Unfortunately, some Amiga TCP/IP stacks do not support p2p links
very well and try to perform ARP here, too :/

However, ARP must be spoken on Eth Port to map local IP addresses to the
Ethernet MAC addresses. Whenever an IP packet (after NAT) is ready to be sent
out via Ethernet then we have to find out what Ethernet MAC address has the
destination. If the destination IP is on the local sub net (determined with the
netmask of the local network) then ARP is used to find the corresponding MAC.
Otherwise we ARP the gateway (gw) IP address on the local sub net and send
the packet there.

To make ARPing more performant plipbox keeps an ARP cache. This is a table
of IP to MAC address mappings that were already used on the local sub net.

The MAC address of the local ethernet adapter on the plipbox is set by the
firmware. The default firmware already ships with a pre-defined address. If
you use multiple plipboxes in one local sub net then you have to alter this
address for individual devices.

Regarding MTU size this approach actually can apply two sizes, one for each sub
net. While the Ethernet is typically set to 1500 the PLIP link is not limited
to this value and can use arbitrary ones. However, if the PLIP MTU is larger
than 1500 then the plipbox needs to fragment the packets but this is currently
not implemented.

In summary, the NAT approach of the firmware works well but needs quite a lot
of configuration. Furthermore, the NATing applied causes trouble to protocols
that use IP addresses inside the protocol. Most notably, the FTP needs to use
passive mode in this setup to work correctly.

Another cause for trouble in this setup is the NAT that is already applied in
most local home networks when reaching the Internet. E.g. a DSL router NATs all
outgoing traffic. So a double NAT is applied to all Amiga packets when they run
through plipbox, local network, and finally the Internet.

2. MAC bridge
-------------

Starting with version 0.3 plipbox the NAT approach is replaced by a MAC bridge.
This bridge is more "transparent" than NATting and should overcome the problems
associated with NAT.

The old Amiga network device (magplip.device) that offered a point-to-point
link is replaced with a new device driver (plipbox.device) that announces an
Ethernet compatible device. The TCP/IP stack on the Amiga now directly
generates Ethernet packets with a 1500 MTU and transfers them to the plipbox.
There the frame is directly (i.e. without any alteration) passed to the
Ethernet adapter and send to the local network.

Also any incoming frame on the local network is passed to the Amiga plipbox
device driver and deliverd as an Ethernet packet to the TCP/IP stack.

                               +-----plipbox-----+
        1a:11:a1:a0:47:11      |            1a:11:a1:a0:47:11        
          +-------+ ARP/IP +-----------+      +----------+ ARP/IP
          | Amiga | <----> | PLIP Port |-COPY-| Eth Port | <---> Local Network
          +-------+        +-----------+      +----------+  lan
         192.168.2.133         |                 |              192.168.2.x
        plipbox.device         |                 |        mask: 255.255.255.0
                               +-----plipbox-----+          gw: 192.168.2.1

Now the plipbox firmware is most transparent and essentially looks like an
ethernet device directly attached to the Amiga. In this setup no NAT is applied.

You now configure your Amiga's TCP/IP stack like it is directly attached to the
local network. Give yourself a static IP or use DHCP, set the local network's
net mask, and the default gateway. Also the stack now needs to do ARPing to map
the IP addresses to Ethernet MAC addresses and it manages an own ARP cache.

The plipbox firmware is now very slim and zero-config. The only essential
parameter is the MAC address of the Eth Port. It has to have the same value
as it is used in the plipbox.device driver. The address will be automatically
transferred by the driver to the firmware on startup. By default both use
the mac address 1a:11:a1:a0:47:11. 

The device driver uses the mac address to generate the correct source address
in each frame while the plipbox firmware uses the mac address to setup a HW
Ethernet filter so that the Eth Port only reports packets for this or the
broadcast address.

In summary, with the new approach the Amiga has a bit more to do (e.g. handling
ARP packets) but all problems that were observed with NAT are gone now.

EOF

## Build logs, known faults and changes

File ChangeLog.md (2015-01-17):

plipbox: ChangeLog
==================

version 0.1 (22.7.2012)
-----------------------

- initial public release
- converted plip2slip code base and added ethernet support
- introduced a NAT device in firmware that connects a point2point link from
  the Amiga with the local Ethernet
- added DHCP on Ethernet link
- initial HW support: Arduino 2009

version 0.2 (2.9.2012)
----------------------

- added HW support for AVR-NET-IO board

version 0.3 (19.5.2013)
-----------------------

- major redesign: removed NAT device and introducded MAC bridge, i.e.
  plipbox behaves like an Amiga Ethernet adapter and bridges all packets
  from there without alteration
- dropped lots of network code found in plipbox that is not needed for the
  MAC bridge
- rewrote and renamed Amiga SANA-II plipbox.device to be an Ethernet driver
- added a Python-based software emulation for the plipbox that operates with
  a patched FS-UAE Amiga emulator
- new approach makes the device zero-conf. Just attach and it works.

version 0.4 (01.6.2013)
-----------------------

- added hardware description for plipbox nano hardware
- added schematic and board design for plipbox nano base board
- added new firmware -nano for new plipbox nano pinout
- Amiga driver unchanged and stays at 0.3

version 0.5 (30.11.2013)
------------------------

- plipbox device now automatically receives its MAC address from driver
- you can change your MAC address with SANA-II command in software
  (if your TCP/IP stack supports it, e.g. Miami DX or Roadshow)
- plipbox device maps online/offline state to Ethernet module and
  disables it if devie is offline
- parallel line protocol completely rewritten to use a client server model
- added optional Ethernet full duplex support
- added optional Ethernet flow control
- improved device statistics
- added error log

version 0.6 (17.01.2015)
------------------------

 - new fast burst protocol for raw parallel transfers of up to 235 KiB/s
 - see benchmark.md for detailed performance values
 - cleaned up firmware and driver code
 - rewrote firmware to handle a full ethernet frame in SRAM
 - reduced parameters in firmware -> simplified usage
 - added new test modes to allow detailed benchmarking of all system components

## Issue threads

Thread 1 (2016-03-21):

Assistance needed connecting Strobe to EXT

Cjsnet, 2016-03-21:
Hi, you're hard to get hold of! Having tried Twitter to no avail, and finding Wordpress won't accept comments at this time, I'd be most grateful of a response here or anywhere.

I simply have 2 questions for the AVR-NET-IO:

1. Which pin is pin 1 of the EXT? A photo would be great showing the Strobe wire connected.
2. Does the AVR-NET-IO require power or will the Amiga parallel port power it?

Thanks in advance! :)

cnvogelg, 2016-03-28:
Hi,

just having a RL with 3 little ones :) So updates/comments usually take
time...

1. I just added a picture to the plipbox hardware page
2. Yes. Parallel port is not powerful enough to supply the circuit (10mA
vs. 300mA...)

Best,
Chris

Am 22.03.16 um 00:13 schrieb Cjsnet:
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

Cjsnet, 2016-03-28:
The picture at http://lallafa.de/blog/wp-content/uploads/2012/07/avrnetio_strobe.jpg is great, thank you. Sorry for asking in more than one place, I understand now about the little ones! Thank you and congratulations.

Cjsnet, 2016-04-14:
Hi again, would you please kindly offer your help with flashing firmware to the AVR-NET-IO as per my 2 questions here: http://eab.abime.net/showthread.php?p=1083815#post1083815

Replying at that thread may be best. Thank you in advance.

Patiently yours,

Cjsnet, 2016-04-28:
Please note a lot of errors with your instructions, that have led to a lot of dead ends and confusion:

A) https://github.com/cnvogelg/plipbox/blob/master/doc/src/amiga.md
2.2:
- The URL for Network Boot Disk is wrong (take care with trigger happy clipboard pasting)
- df0:s/Prefs/Env-Archive/nbddriver should be df0:Prefs... (no s/)
- "Adjust your AmiTCP:bin/startnet and rename the interface to plipbox0" makes no sense. What is "the interface". No such reference in "startnet". See http://eab.abime.net/showpost.php?p=1086435&postcount=11

B) https://github.com/cnvogelg/plipbox/blob/master/doc/src/firmware.md
- Please make it much clearer on the "Hardware" page and here, that the AVR-NET-IO *must* use ISP requiring another purchase to go that route. I lost a day of life trying to flash it via USB Serial, because you only mention that further into the document, not at the start – and most users "start" at the start, *then* work their way down.
1.3:
- URL for "USBasp" and "kit" are wrong links.

Thank you for all your work and I hope this feedback is useful so future users attempting the project don't have the same problems I did.

I look forward to your reply about "the interface" above.

cnvogelg, 2016-05-01:
Thanks for the corrections.
I updated the docs in 85a5737.

The AmiTCP section was cleaned up. Initially it contained information for both vanilla AmiTCP installs and the Network Boot Disk. Now I focus on the boot disk alone to avoid confusion.

Cjsnet, 2016-05-01:
Thank you.

1. Before "Insert this disk into your favorite Amiga emulator and perform
the following steps to prepare the disk:" you need a step, "Run the disk
once and let it configure itself". Without that step, first boot setup of
it will delete plipbox.device as an unwanted file.

2. Please clarify, where/how do I "set plipbox0." IE what does "set" mean?
Type?

Thanks again!

On Sun, May 1, 2016, 12:18 Christian Vogelgsang <notifications@github.com>
wrote:

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

Cjsnet, 2016-05-03:
Please assist at http://eab.abime.net/showpost.php?p=1087340&postcount=16
Can't get plipbox online using these instructions. Thank you!

cnvogelg, 2016-05-04:
I just patched the disk myself (last time I did this was ages ago :)) and re-wrote this section again.
Hope this helps...

Cjsnet, 2016-06-02:
Things are working great now and I finally am able to send and receive email on an A500. Quite a feat!

2 issues left:

1. The Internet seems to get disconnected after some time (20 mins+) and I have to reboot. Is there something I should be doing / some command, to keep the net alive? It feels like the AVR-NET-IO is failing. (The ethernet LED keeps flashing random patterns so data is being sent/received.)

2. If I simply power cycle the A500 at that point, user-startup fails to get AmiTCP to connect, whereas on a full power cycle of the plipbox itself, the net works perfectly on startup. Therefore, for some reason the AVR-NET-IO needs to be turned off then on every 30 mins in order to keep the net alive.

Any ideas please?

Cjsnet, 2016-11-19:
@cnvogelg RSVP to the message above.

cnvogelg, 2016-11-19:
Please record serial logs from the device from startup until the disconnect happens. Maybe we can see here whats happening.

Cjsnet, 2016-11-19:
@cnvogelg Good idea. How do I do that?

cnvogelg, 2016-11-19:
The AVR-NET-IO has a RS232 serial connector (DB9) next to the ethernet port. You need to connect your PC to this port to record the log. Typically, you'll need a null modem cable and a RS232/serial to USB converter.
Then launch a terminal program on your PC (like TeraTerm on Windows) select the COM port of the USB adapter and set 57800 Baud Rate. There you should see the welcome message of the pillbox after power on and errors if something went wrong.

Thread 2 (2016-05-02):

Is PIO test mode ping capable?

tobox, 2016-05-02:
According to the documentation in https://github.com/cnvogelg/plipbox/blob/master/doc/src/firmware.md#34-pio-test-mode the PIO test mode should answer ping requests. In my case, it did not, but UDP packets were successully replied. A quick inspection of the source code seemed to indicate that the PIO test mode does indeed only handle ARP and UDP, but no ICMP. Am I missing something or is there an error in the documentation?

Regards
Thomas

cnvogelg, 2016-05-04:
Well spotted. Ping is indeed missing in this mode. I'll correct the docs...

patrikaxelsson, 2022-12-30:
@tobox: can this issue be closed after the doc update?

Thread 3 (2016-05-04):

plipbox.device 0.6 does not work

apaul007, 2016-05-04:
Hello,
i tried the plipbox.device 0.6 with a crasbe plipbox and an AVR NETIO. Both using 0.6 firmware. No function. With the device version 0.5, both hardware is working. (Hardware left on 0.6 fw)

Regards
Andreas

cnvogelg, 2016-05-04:
The 0.6 driver uses fast burst mode on parallel by default. Thats the major change in this version.
I suspect that this mode does not work on your HW.

You can disable the burst mode in 0.6 with:
```
echo NOBURST > EnvARC:sana2/plipbox.config
```

What Amiga system are you using?
It would be very helpful to get serial output of the plipbox to have a chance for further diagnosis...

apaul007, 2016-05-04:
I tried this already but just found out plipbox.config was in wrong path. Now, with correct location: If NOBURST ist set the 0.6 device works.
My hardware is an Amiga 2000 with GVP G-force 030 @ 25 MHz and an Amiga 1200 with Blizzard 1230 IV @ 50 MHz. Both running OS 3.1

From which mode do you need debug output? I have a serial interface ready at the NETIO.

cnvogelg, 2016-05-05:
PB Test Mode is best suited to debug these kinds of problems (see section 3.5).
It only transfers packet data across the parallel port.

Start with sending single packets manually with 'p' and see if errors occur and record the output.
Then also try an automatic session with 'a' and let it run for some time. Show statistics with 's'.

apaul007, 2016-05-10:
I tried PB Test Mode with the A2000 and the AVR NETIO plipbox. Between there is a 1m parallel port cable. Amiga runs dev_test -d plipbox.device

Here is some serial output. PB Test mode, auto

cnt  bytes    err  drop rate
0000 00000000 0000 0000 0000.00 KB/s rx plipbox
0000 00000000 0000 0000 0000.00 KB/s tx
0000 00000000 0000 0000 0000.00 KB/s rx pio
0000 00000000 0000 0000 0000.00 KB/s tx
cnt  bytes    err  drop rate
0000 00000000 0000 0000 0000.00 KB/s rx plipbox
0000 00000000 0000 0000 0000.00 KB/s tx
0000 00000000 0000 0000 0000.00 KB/s rx pio
0000 00000000 0000 0000 0000.00 KB/s tx
000060.7713 [AUTO] off

single p events

000066.2320 [RX:22] ok n=1514 d=5151 v=0073.48 KB/s  +req=+0018
000066.2650 [TX:11] ok n=1514 d=5022 v=0075.36 KB/s
000067.2692 [RX:22] ok n=1514 d=5128 v=0073.81 KB/s  +req=+0018
000067.3021 [TX:11] ok n=1514 d=5016 v=0075.45 KB/s
000067.6785 [RX:22] ok n=1514 d=5101 v=0074.20 KB/s  +req=+0018
000067.7118 [TX:11] ok n=1514 d=5100 v=0074.21 KB/s
000067.8840 [RX:22] ok n=1514 d=5158 v=0073.38 KB/s  +req=+0018
000067.9170 [TX:11] ok n=1514 d=5024 v=0075.33 KB/s
000068.0804 [RX:22] ok n=1514 d=5151 v=0073.48 KB/s  +req=+0019
000068.1136 [TX:11] ok n=1514 d=5064 v=0074.74 KB/s

salocinx, 2016-11-15:
Hi - I have currently the same issue using firmware 0.6 on my A1200 with Blizzard 1230 IV, A3000D/16 and A600/ACA620. It does not work with 0.6 but fine with 0.5 if I flash the Arduino to 0.5 and using device driver 0.5. Altough, on my A3000D/A3640 and my A4000/060 it works fine with 0.6.

I am using MiamiDX10 on all machines. But the "NOBURST" flag in ENVARC:SANA2/plipbox.config has no effect at all on the machines v0.6 is not working. Do I need to place plipbox.config at another place when using MiamiDX10 instead of AmiTCP?

Thanks.

cnvogelg, 2016-11-19:
Hi,
the config file is hard-coded in plipbox.device to `ENV:SANA2/plipbox.config`.
It is read by the device itself therefore it does not matter what TCP/IP stack is used.

Lotusshaney, 2017-04-28:
Thanks, This fixed my problem on an A4000/GVP 040 WB 3.9 with pillbox v0.6 not working at all.  I had response times on a trace route of over 3000 MS !

Lotusshaney, 2017-05-05:
FYI,  I just updated my Amiga A4000 with boingbags 3&4.  One of these contains a fix for Genesis for small packet corruption.  I can now run my Plipbox without NOBURST enabled and speeds have gone from 55,000-60,000 cps to 104,000 cps using iBrowse !!!

salocinx, 2018-06-02:
> Where exactly is this "echo NOBURST > EnvARC:sana2/plipbox.config " go? The Startup-Sequence, User-Startup or what? It would be nice if there was a little more clarification.

This is an AmigaDOS command. You need to enter this line to a CLI or Shell window. It basically creates a new file called `plipbox.config` if not yet existent and does simply write "NOBURST" into that file. The plipbox driver looks up this file when started and reads out it's content and does the appropriate processing; in this case, disabling the burst-mode introduced in revision 0.6 of the plipbox driver. Please re-check if `plipbox.config` is indeed at the `EnvARC:sana2` folder. I did test this and worked always fine.

I don't have additional information on the /S switch myself; maybe somebody else?

soydemadrid, 2019-08-10:
Hi I can't get my Plipbox on A4000 with MiamiDx to work.

I've also tried the echo NOBURST > EnvARC:sana2/plipbox.config

too but it makes no difference...

DHCP isn't working, and if I use static addresses it just says it is online but anything I ping gets 100% packet loss.

I have the boingbangs already updated too.

It may be that I have a faulty parallel port as I know my serial port doesn't work.

I bought a Hypercom board so I have more serial and parallel ports which I know do work. How do I set the Plipbox to work on my Hypercom parallel ports instead of the built in default parallel port?

Thanks for any help

10MARC, 2019-12-10:
I had the same issue as Soydemadrid above - 100% the same. I had bought a Plipbox using a cheap Thinary Electronic Arduino, and I could not even flash it back to V .5 - It would not work with any version of the AVRDUDE software at all. I could use a terminal program to log into it, though.
I solved my issue by buying a higher quality Arduino right from Arduino - I still had to flash it to V .05 to get it to work. It was totally unresponsive to the "NOBURST" trick in plipbox.config - It just did not care and would never see the network. Downgraded to .05 and it came online and worked within about 5 seconds.
I tried it on an Amiga 2000 with a GVP 040 card and an A1200 with a Blizzard '40 card. If I could flash the cheap Arduino I could probably get it working, too.
Maybe there is an issue with the V .06 firmware?

salocinx, 2019-12-10:
The Chinese Arduino clones use usually the CH340 USB to Serial chip. The Atmel CPU is the same for the Chinese and original Arduino boards. Therefore you need to install the appropriate CH340 driver in order to flash these boards. [Here's a link to the CH340 driver](https://cdn.sparkfun.com/datasheets/Dev/Arduino/Other/CH340DS1.PDF).

10MARC, 2019-12-10:
@salocinx Thanks for that info - I do have those drivers - the guy who assembled the Plipbox linked them to me. Using a terminal program to get into the Arduino works 100% and I can change settings, it is just reflashing which does not work. It always reports that it cannot connect to the programmer because it is out of sync. Tried every BAUD rate known to man, and three different programs. The new Arduino board and a second one I have both reflash without much trouble - so I am pretty sure it is a funky board.
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
craziazkowboi, 2023-05-22:
I don’t know if this would work for you too, but try putting a heatsink on the ethernet board cpu.  It has worked miracles for me - A1000 with a 68030-TK2 and using Burst mode.  Never worked prior, works flawlessly now.

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

salocinx, 2023-05-22:
Some also say, that old capacitors might be the problem. Signal quality on the parallel port probably improves with new capacitors.

craziazkowboi, 2023-05-22:
Yes, yes, I also had to re-cap my Amiga 1000 before I could use the Plipbox reliably.

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

powaking, 2023-05-22:
My A1200 was professionally recapped. I will try and see if I can get a heat sink on the Ethernet cpu. I am using a pistorm32 right now. I can try with my Blizzard but doubtful if that will show any difference.

salocinx, 2023-05-22:
The ENC28J60 Ethernet controller chip indeed can get hot. As long as you can put your finger on it, it should be fine. But as craziazkowboi already mentioned, it's normally a good thing to cool it with a little heat sink. It's worth a try.

craziazkowboi, 2023-05-23:
I also switched to using USB to power my POlipbox rather than the barrel connector, I think this also helped along with the heat sink.  If that doesn’t work, I got nothin' :)

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

salocinx, 2023-05-23:
You may want to post a picture of your device. Have you installed pull-up resistors on the data and control lines?

powaking, 2023-05-23:
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

this is my plipbox. I did not build it, it was given to me as a gift. As you can see I can not use USB to power the device and must rely on the barrel connector. I don’t feel anything being warm enough to warrant a heat sink.

salocinx, 2023-05-23:
The ENC28J60 chip which is sometimes getting hot, is beneath the Arduino Nano, on the middle PCB. Can you remove the Arduino Nano (socket or soldered) ? If so, you could run the Plipbox for some time and then turn-off the Amiga and remove the Arduino Nano and check the temperature of the chip beneath.

craziazkowboi, 2023-05-23:
Before adding any heat sinks - the chip in the middle is the one to add a heat sink too.  The Nano Uno runs very cool and does not need a heat sink at all.

￼

OK…I got a bit excited and put heatsinks on everything, but the only one needed was the one in the middle, just behind the ethernet socket.

￼

Hope this helps!

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

powaking, 2023-05-24:
Just for giggles I downloaded the Network Bootdisk for Amiga and on the first boot after setup it failed to connect. Sure enough there was no plipbox.config. I created one and set the NOBURST and on reboot it connected immediately. This just proves its not my MiamiDX config or something.

I then ordered some microchip headsinks and placed them on the chip. Removed the NOBURST and power cycled everything. Again no dice. Just won't connect without the NOBURST. Not sure what else to try other than A) Find a reliable PCMCIA ethernet card thats reasonably priced or B) wait for the Pistorm team to get the Pi's wifi working.

craziazkowboi, 2023-05-25:
Well, a PCMCIA card or PiStorm will always be much faster than the Plipbox can ever do, but less sexy :). PiStorm can already use the WiFI using Musashi, I have a link on my blog to the instructions for setting this up (Scroll down to the PiStorm section and look for the Retro32 link).  https://amiga1000parceiro.blogspot.com/2023/01/amiga-1000-68030-upgrades.html

I like the Plipbox, and it is does everything I need - honestly internet surfing on the Amiga is not a long term viable option, it’s a novelty.  UHC Tools are awesome though!  My plipbox.config contains one line as follow:

TIMEOUT=800000 PRI=25

And is stored in /EVARC:SANA2/plipbox.config

And my DEVS:NetInterfaces/plipbox file is set to:
configure=dhcp
hardwareaddress=1a:11:a1:a0:00:01

debug=yes

iprequests=128
writerequests=128

However I do not use the 'downgoesoffline=yes’ option - I have commented this out in case I want to use it in the future.  With his turned on, I had some issues at one point.

I had also changed my nano board to an original Arduino nano - you’ll need to be handy with a soldering iron and patient if you go this far.  And that meant I also re-programmed my nano first to v0.5, and then to v0.6.  I also power using the USB input, not the barrel connector - this was also essential for me.

I don’t know if this would work for you, but if you have nothing to lose, it’s fun :)

Regards,

> On 25 May 2023, at 7:38 am, powaking ***@***.***> wrote:
>
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

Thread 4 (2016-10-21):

terminal looping

hojo181, 2016-10-21:
Hi, I have installed the 0.6 software on a arduino nano clone based on the 328p chip, when I start the terminal under windows to test the plipbox i see the same message looping:
m: mac address   1A
Welcome to plipbox 0.6 20150117
by lallafa (http://www.lallafa.de/blog)

m: mac address   1Aÿ
Welcome to plipbox 0.6 20150117
by lallafa (http://www.lallafa.de/blog)

m: mac address   1A
Welcome to plipbox 0.6 20150117
by lallafa (http://www.lallafa.de/blog)

and so on.

What went wrong?

cnvogelg, 2016-10-24:
Could you try to remove the ethernet shield and try again?
I suspect that the ethernet shield draws to much power on the 3.3v rail when it gets activated during startup. You then need a more powerful 3.3v regulator.

hojo181, 2016-10-25:
I removed the ethernet shield and nothing changed, I programmed again of the nano clone and nothing changed. To program the nano I use this :http://www.ebay.it/itm/182268876593?_trksid=p2057872.m2749.l2649&ssPageName=STRK%3AMEBIDX%3AIT

hojo181, 2016-10-25:
Ok, i will try

Il 24/ott/2016 21:03, "Christian Vogelgsang" <notifications@github.com> ha
scritto:

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

cnvogelg, 2016-10-28:
Another reason for automatic reset is the watchdog. Please make sure that the fuses are correctly programmed so that it is disabled.

hojo181, 2016-10-29:
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
I changed some option in avrdudess, and now it work :)
I was following the instrution found on a web page, that suggested to
let avrdudess to read the fuses & lock bits and the lb, that caused some
trouble, than i changed the preset voice in to arduino nano atmega328p,
that gave me different value for the fuses and lock. After a flash I
have the config menu of the plipbox :)
�FV��RA� JdAb����Br  TB �R	@A2

Welcome to plipbox 0.6 20150117

by lallafa (http://www.lallafa.de/blog)

m: mac address   1A:11:AF:A0:47:11

fd: full duplex  00

fc: flow control 00

tl: packet len   05EA

tt: packet type  FFFD

ti: ip address   192.168.002.222

tp: udp port     1A90

tm: test mode    00

Press <return> to enter command mode or <?> for key help

000000.0581 [BRIDGE] on

000000.0624 pio: init: enc28j60ERROR:01

VERBOSE: ON

this is the nano only without the ethernet shield, I will try with the
shield later :)

Closed 2016-11-19.

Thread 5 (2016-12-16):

Which IDE for AVR code ?

salocinx, 2016-12-16:
Hi - I am feeling like hacking a bit :-) What IDE do you use for developing the AVR part? Could you offer a project file?

salocinx, 2016-12-20:
Okay I just used gedit and avr gcc to compile on my Debian system. Worked fine. I slightly changed your code in order to enable a LED indicator on PD2 when IP packets are sent and received. Would be nice if you could include that in your next official release :-)

Here's a video of the result: https://www.youtube.com/watch?v=WCf1XnFd_Vs&feature=youtu.be

cnvogelg, 2016-12-22:
Hi, same here. I use SublimeText for all coding stuff. Its an editor with a nice directory-based "project" mode. Building is triggered from the editor by calling make.
Patches are welcome. Just prepare a PR.
Currently, I prepare a small test firmware to debug the burst issues...

salocinx, 2017-01-08:
Okay, I will give SublimeText a try and see if I get into your code, which is very well structured by the way 👍 . I have some experience with ARP/IP and hope I will be able to support you a bit. I will open two other issues I ran into when testing the Plipbox recently (and others did too).

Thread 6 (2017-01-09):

MiamiDX: Error (3,1) trying to configure the SANA-II device.

salocinx, 2017-01-09:
MiamiDX throws the following exception when the Plipbox is powered on after the Amiga is powered on:

> Miami Deluxe Request
> Error(3,1) trying to configure the SANA-II device.

The Plipbox works fine if you power on the Plipbox first then power on the Amiga.  If you reset the Amiga after the Plipbox has been working normally, MiamiDX complains that it doesn't get a response to the DHCP request.  Appears that the Plipbox is in some undetermined state when the Amiga gets reset and it doesn't get reset unless you power things off then on again in the right order.

This seems to be a kind of reset issue. Is there there some separate software which will do a Plipbox reset prior to trying to connect with MiamiDX ?

cnvogelg, 2017-01-16:
well, actually this is not a supported use case. always power on the plipbox first and before launching the device driver.

I admit that having a reset command for the device would be a good idea. I am currently reworking the protocol and I'll keep this in mind.

salocinx, 2017-01-19:
Great, some kind of software reset would be lovely. Many thanks for your efforts!

salocinx, 2017-10-11:
Connecting the Amiga _RESET signal (pin 25 on A1000 and pin 16 on all other Amiga models) with the Arduino reset pin resolves the problem. Also connect the Arduino reset pin with the ENC28J60 reset pin. This way, the Plipbox will always reset as soon as the Amiga is reset.

Lotusshaney, 2017-10-11:
Can you detail where the reset pins are on the Arduino and the ENC28J60 ?

salocinx, 2017-10-11:
These are labeled with "RST" on both devices, the Arduino and the ENC28J60 modules. Just make a connection from Amiga Parallel (_RESET) -> Arduino (RST) -> Ethernet (RST). For the connection between Amiga _RESET and Arduino RST you might want to use a standard diode (e.g. a 1N4148) to protect your Amiga additionally.

Lotusshaney, 2017-10-16:
Anode or cathode to the Amiga plug ?

Sent from my iPhone

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

salocinx, 2017-10-16:
Cathode to Amiga and anode to Arduino.

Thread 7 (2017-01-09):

Blocking entire LAN

salocinx, 2017-01-09:
A few times the Plipbox snaps into a very strange state. In that state, my extra send/receive indicator LED does not extinguish anymore and the Plipbox seems to flood the LAN with network packets. When this is the case, no computer attached to the LAN is able to send/receive any network traffic anymore. Restarting the Plipbox solves the issue.

cnvogelg, 2017-01-16:
by default plipbox does flow control on the ethernet link. if this is not handled correctly you can stall your network.
you can disable flow control with the `fc` command in the command mode on the serial console.
to debug this issue it would be helpful to get a serial log of plipbox's output

salocinx, 2017-01-19:
Okay I managed to connect with CoolTerm/Windows to my Plipbox. I did tests with firmware 0.5 and 0.6. The Plipbox with firmware 0.6 did not jam the network with the procedure described in my initial post, whereas the Plipbox with firmware 0.5 did.

Here are the logs for version 0.5 after shutting down the Amiga while downloading a larger file:

`Welcome to plipbox 0.5 20161220
by lallafa (http://www.lallafa.de/blog)

fd: full duplex  00
fc: ETH flow ctl 01
fe: filter ETH   01
fp: filter PLIP  01

dd: dump dirs    00
de: dump ETH     00
di: dump IP      00
da: dump ARP     00
dp: dump proto   00
dl: dump plip    00

la: log all cmds 00

enc28j60: rev 07 half duplex
000107.6788 pbp(rx): online: mac=1A:11:AF:A0:47:11 ver=00.05
000107.6894 pbp: link up
000107.6940 eth: link up
000144.8281 io: 22 43 1514 000000.0183 000000.0026 `

Here are the logs for version 0.6 after shutting down the Amiga while downloading a larger file (no jamming):

`
Welcome to plipbox 0.6 20150117
by lallafa (http://www.lallafa.de/blog)

m: mac address   1A:11:AF:A0:47:11

fd: full duplex  00
fc: flow control 00

tl: packet len   05EA
tt: packet type  FFFD
ti: ip address   192.168.002.222
tp: udp port     1A90
tm: test mode    00

Press <return> to enter command mode or <?> for key help
000000.0581 [BRIDGE] on
000000.0624 pio: init: enc28j60: ok! mac=1A:11:AF:A0:47:11 flags=04 rev=07
000001.3418 FIRST INCOMING!
000001.3474 OFFLINE DROP: 00D7
000002.5289 cmd=00?? ERR:04
000004.3698 OFFLINE DROP: 00D7
000007.3972 OFFLINE DROP: 00D7
000010.4244 OFFLINE DROP: 00D7
000013.4518 OFFLINE DROP: 00D7
000016.4791 OFFLINE DROP: 00D7
000019.5067 OFFLINE DROP: 00D7
000022.5338 OFFLINE DROP: 00D7
000025.5611 OFFLINE DROP: 00D7
000028.5884 OFFLINE DROP: 00D7
000031.6158 OFFLINE DROP: 00D7
000034.6431 OFFLINE DROP: 00D7
000037.6704 OFFLINE DROP: 00D7
000040.6980 OFFLINE DROP: 00D7
000043.7251 OFFLINE DROP: 00D7
000046.7525 OFFLINE DROP: 00D7
000049.7798 OFFLINE DROP: 00D7
000052.8072 OFFLINE DROP: 00D7
000055.8345 OFFLINE DROP: 00D7
000058.8618 OFFLINE DROP: 00D7
000061.8892 OFFLINE DROP: 00D7
000064.9165 OFFLINE DROP: 00D7
000067.9439 OFFLINE DROP: 00D7
000070.9712 OFFLINE DROP: 00D7
000073.9985 OFFLINE DROP: 00D7
000077.0259 OFFLINE DROP: 00D7
000080.0532 OFFLINE DROP: 00D7
000083.0805 OFFLINE DROP: 00D7
000086.1078 OFFLINE DROP: 00D7
000089.1352 OFFLINE DROP: 00D7
000089.4431 OFFLINE DROP: 00F9
000089.4490 OFFLINE DROP: 005C
000089.6281 OFFLINE DROP: 005C
000089.6342 OFFLINE DROP: 00D8
000089.6401 OFFLINE DROP: 005C
000092.1625 OFFLINE DROP: 00D7
000095.1902 OFFLINE DROP: 00D7
000098.2172 OFFLINE DROP: 00D7
000101.2445 OFFLINE DROP: 00D7
000104.2719 OFFLINE DROP: 00D7
000107.2992 OFFLINE DROP: 00D7
000110.3265 OFFLINE DROP: 00D7
000113.3539 OFFLINE DROP: 00D7
000116.3675 [MAGIC] online
000116.4085 FIRST TRANSFER!
000210.8963 cmd=FF?? ERR:04`

Let me know if and how I can provide you more information on this issue.

salocinx, 2017-10-11:
I guess this issue is also solved by forwarding the _RESET signal to the Plipbox as I described [here](https://github.com/cnvogelg/plipbox/issues/6).

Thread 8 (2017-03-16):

Where to change the MAC address ?

salocinx, 2017-03-16:
Hello - I was looking through your sources, but did not find the line where the static MAC address is defined. Could you please point me to the correct line of code? I would be very thankful for a quick response. Thanks a lot!

cnvogelg, 2017-03-16:
Actually, you can already change the MAC address via the SANA-II interface with S2_CONFIGINTERFACE from your TCP/IP stack.

Amiga side:
[device.c:228](https://github.com/cnvogelg/plipbox/blob/3bc06375b826df271db355415b4e6eeef3783280/amiga/src/device.c#L228)
[server.c:501](https://github.com/cnvogelg/plipbox/blob/3bc06375b826df271db355415b4e6eeef3783280/amiga/src/server.c#L501)

AVR Side:
[param.c:46](https://github.com/cnvogelg/plipbox/blob/3bc06375b826df271db355415b4e6eeef3783280/avr/src/param.c#L46)
[bridge.c:82](https://github.com/cnvogelg/plipbox/blob/3bc06375b826df271db355415b4e6eeef3783280/avr/src/bridge.c#L82)

peterfalk27, 2017-10-01:
Could you please explain the procedure a little more detailed? Do I have to use S2_CONFIGINTERFACE as command in the Amiga Shell/CLI in order to change the MAC address? Is the newly configured MAC address afterwards persistently stored on the Arduino?

gerdovic, 2017-10-02:
I would also be interested in this topic, because I have two Plipoxes and the DHCP fails to assign an IP address to both of them. I guess I need so change the MAC address somehow. Any ideas?

salocinx, 2017-10-10:
I guess that S2_CONFIGINTERFACE is a C API. MiamiDX and Roadshow do implement it, compare to the [Amiga installation guide here](https://github.com/cnvogelg/plipbox/blob/master/doc/src/amiga.md). Unfortunately I didn't found a possibility to change the MAC address by using AmiTCP or Genesis, is that correct?

cnvogelg, 2017-10-10:
Correct, the S2_CONFIGINTERFACE is the SANA II C API for a network driver to accept a MAC address. AmiTCP indeed does not seem to support it. At least a quick scan through the 3.0b2 source code does lead to this assumption.

However, you can alter the mac address via a serial terminal directly at your plipbox device.
With the ``m 00:11:22:33:44:55`` command you set the new address and with ``ps``you store it in EEPROM.

See the [manual](https://github.com/cnvogelg/plipbox/blob/master/doc/src/firmware.md#233-configuration-commands) for details.

salocinx, 2017-10-11:
Thanks for your answer. In your [intro.md](https://github.com/cnvogelg/plipbox/blob/master/doc/src/intro.md) you write the following:

`The address will be automatically transferred by the driver to the firmware on startup. By default both use the mac address 1a:11:a1:a0:47:11.`

Isn't the MAC address overwritten again by the plipbox.device on startup if the MAC address is changed on the Arduino only?

dm9290, 2017-10-22:
I  can confirm AmiTCP 3 changes the mac address back to the default despite changing the mac address on the plipbox and saving to NV ram, and confirming the change was saved by unplugging and reconnecting to plipbox.   This makes the m command basically useless on an Amiga.

dm9290, 2017-10-22:
I found a TCPIP Stack agnostic solution.
Use a HEX editor on plipbox.device.
I used FileX-68K available on aminet -  did a hex search (i.e. unclicked the "string search" button), searched for 1A11AFA04711 and replaced it with 1A11AFA04712 and now my A1200 has a MAC address of 1a:11:Af:A0:47:12 and my A1000 has the default, and both plipboxes exist happily on the same network.

salocinx, 2017-10-23:
Thanks for sharing! Works very fine after rebooting the Amiga.

patrikaxelsson, 2022-12-28:
All TCP/IP stacks on the Amiga has the functionality to specify/override the default MAC address stored on the card.

For example in Roadshow you use the `hardwareaddress` parameter in the NetInterfaces/Plipbox file and in AmiTCP you use the `ADDRESS` parameter for the plipbox line in AmiTCP:db/interfaces file.

The Roadshow part is already detailed in the documentation: https://github.com/cnvogelg/plipbox/blob/master/doc/src/amiga.md#25-roadshow

patrikaxelsson, 2022-12-28:
> All TCP/IP stacks on the Amiga has the functionality to specify/override the default MAC address stored on the card.

Scratch AmiTCP3.0b2 from that statement 😓. The `ADDRESS` parameter feature to set the MAC address was added in AmiTCP4.0.

salocinx, 2022-12-28:
My guess is that the Sana-II specs provide the interface to change the MAC adress, but the question is if the plipbox.driver implements this interface 🤔 Not sure about this, maybe Christian can answer this.

patrikaxelsson, 2022-12-28:
It works fine when I test it with Roadshow at least. The MAC address change is visible in the serial terminal if you are in verbose mode:
```000014.4846 pio: init: enc28j60: ok! mac=1A:11:AF:A0:47:33 flags=04 rev=07```

The funny thing is that this new MAC address is saved in the plipbox - if I cut the power and restart it, it will print the new address at the welcome message:
```
Welcome to plipbox 0.6 20190105
by lallafa (http://www.lallafa.de/blog)

m: mac address   1A:11:AF:A0:47:33

fd: full duplex  00
fc: flow control 00

tl: packet len   05EA
tt: packet type  FFFD
ti: ip address   192.168.002.222
tp: udp port     1A90
tm: test mode    00

Press <return> to enter command mode or <?> for key help
free stack:010E
```

However, if plipbox.device is used without the hardwareaddress override, it will revert back to the default :11 address, so its like plipbox.device does not care which address is saved in the plipbox, which it reasonably should - it would have been a highly useful feature to be able keep the MAC-address in the plipbox, like it is on a normal network card.

The MAC address can also be saved in the plipbox via the command mode as mentioned above:
1. enter
2. m xx:yy:zz:gg:hh:ii
3. ps

However, as plipbox.device does not care about what is saved, it is not useful.

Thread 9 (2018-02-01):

Possible Bug in server.c?

MHeinrichs, 2018-02-01:
in the amiga driver server.c Im couious about line 391:
The way the for-loop terminates, it doesn't traverse the list until the last element but till the 2nd last.
Is that OK?

cnvogelg, 2018-02-01:
It looks strange but its correct. This is the right way to iterate an Exec list. These data structures have a "virtual" node (in the list structure itself) at the head and tail of each list. Therefore you have to stop iterating through the data nodes at the 2nd last one.
See e.g. [Exec Lists and Queues](http://wiki.amigaos.net/wiki/Exec_Lists_and_Queues) for details.

Closed 2018-02-01.

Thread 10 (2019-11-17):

plipbox and Linux on the Amiga

berlincount, 2019-11-17:
Hello,

I've got AmigaOS with MiamiDX pinging my network happily, but don't know whether it'd be possible to use it under Linux on the Amiga (https://github.com/torvalds/linux/blob/master/Documentation/networking/PLIP.txt is the Linux side for that) .. do you know whether someone has done that, or whether there are other efforts to do it?

What do you think might additionally be require? .. Linux expects a Point-To-Point connection and I so far can only guess the necessary parameters - I'll have to use the source more I guess.

Thanks for this great device, and thanks in advance for and ideas or pointers!

cnvogelg, 2019-11-18:
unfortunately the plipbox and the PLIP Linux driver only share the term PLIP as they transfer IP packets across a parallel link. There the similarities already end... plipbox uses a custom protocol to talk to the microcontroller on the board.

To support this on Linux you have to write a custom driver that implements this protocol.

berlincount, 2019-11-18:
**sigh** by now, I guessed as much.

Is there a protocol documentation, or will I have to extract that from the sourcecode?

cnvogelg, 2019-11-18:
use the source :)

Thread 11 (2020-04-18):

Possibly do 2E transfer instead of 3E

niklasekstrom, 2020-04-18:
Hi Christian,

I was looking at your parallel port communication code, and at your blog https://lallafa.de/blog/2015/09/amiga-parallel-port-how-fast-can-you-go/, and I was thinking that by doing a small optimization it might be possible to do 2E reads and writes instead of 3E.

I did the change as a commit here: https://github.com/niklasekstrom/plipbox/commit/4e5b1ecefaef79bef1dbcd67cdff6ebc5c1d99e0

My thinking is that the bset/bclr instructions are read-modify-write instructions, so an instruction is first doing a read from the CIA register of the old value and then a write to the CIA register of the updated value. By instead doing a single write it should be possible to remove an access to a CIA register, which saves one E-cycle.

Here I'm assuming that you have an accelerator which is sufficiently much faster so that the instruction fetch time is hidden.

Note that I don't own a plipbox myself so I haven't had a chance to test this. I'm not sure if the AVR-side will be able to keep up at the higher pace.

Feel free to close this issue if this suggestion wouldn't be useful.

niklasekstrom, 2020-05-07:
I have now verified that this method works, with this parallel port to SPI adapter: https://github.com/niklasekstrom/amiga-par-to-spi-adapter.

cnvogelg, 2020-05-08:
2E is the way to go. I already use it in my follow up project [amiparbox](https://github.com/cnvogelg/amiparbox). The avr part is written in assembler now to have robust transfers. For the new teensy 3.2 arm support C is fast enough.

niklasekstrom, 2020-05-09:
I see, cool. From a very quick glance at your amiparbox repo, I guess the solution I came up with is a bit simpler, as the AVR is acting as a "glorified shift register" that shifts out SPI bits at >8x the rate that it receives bytes from the Amiga. Any processing needs to be done by the Amiga. One benefit is that there is no buffering in the AVR, so the time until the Amiga receives the transferred data is minimal.

Do you have any plans to update plipbox to do 2E? Otherwise I guess this issue could be closed.

Once I receive a ENC28J60 module and can test that it works with my adapter and Mike Sterling's [driver](https://github.com/mikestir/k1208-drivers/tree/master/net) I think it should be possible to do a firmware upgrade of an existing plipbox device and run my firmware and software instead to do 2E transfers (assuming that ends up giving better performance).

cnvogelg, 2020-05-09:
I really like your project, too. Its simple but very effective :)

The goals with the amiparpbox project are a bit different: I want to provide access to all of the mcu's interfaces including SPI, I2C, and even serial or GPIO and therefore I am developing a protocol on the parallel port that allows to multiplex those data channels. Second I want to offload the Amiga as much as possible and implement drivers (SD Card, Network, Display I/O, ...) on the MCU so that the channels only transport "high-level" data like network packets or data blocks of an sd card. On the Amiga side you have a single device that allows to access the multiplexer (called pamela.device) and standard devices like block devices or sana2 devices use the pamela.device to access their data channels on the amiparbox.

Next to the new teensy 2.0 and teensy 3.2 boards developed for amiparbox I still support the classic plipbox HW and even support an sd card add on there. So with amiparbox SW ready (hopefully some time in the not so distant future :)) it will completely replace the plipbox SW. Therefore develop on plipbox is stopped for now and I focus on amiparbox only.

If the amiparbox projects sparks your interest then I'd be more than happy if you give it a try... Unfortunately, currently the full SW stack is not finished yet and user docs are missing completely :( Feel free to ask if you need support...

drummerjoe, 2021-02-02:
Excited to see where this goes.  I love my Plipbox.

Closed 2024-12-31.

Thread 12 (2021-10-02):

060 device support?

AndyBlake, 2021-10-02:
Hiya
Which device should I use if I have an 060 CPU? Does plipbox support that cpu?
Kind regards
Andy

salocinx, 2021-10-03:
You can use the 040 device for the 060 CPU. Works fine in my A4000/060.

AndyBlake, 2021-10-03:
Thanks, I'll try that out

On Sun, 3 Oct 2021, 13:45 Nicolas Baumgardt, ***@***.***>
wrote:

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

patrikaxelsson, 2022-12-29:
@AndyBlake: please close the issue if you have no remaining problems with this

Closed 2022-12-29.

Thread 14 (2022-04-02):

Compatibility question: Blue Pill

f-bone, 2022-04-02:
hi there!

congrats for you excellent work. I need to ask if I can use a few fake blue pill boards I have laying around which do not pass the greaseweazle blinky test but otherwise can be flashed to an "arduino-combatible" board. excuse my noob-ness.

br,
george

salocinx, 2022-04-02:
Hi George. I recently had problems with newer Arduino Nano V3 bought from aliexpress. They don't work anymore with this firmware (0.6). Did not try with 0.5. However, they work for my other Arduino projects just fine. Interesting point, need to check this greaseweazle blinky test :-)

f-bone, 2022-04-03:
the blue pills that fail the blinky test - you must load that using a UART-TTL are supposingly missing some functions. but if that is not a problem for this project it'd be nice not to throw them in the recycle bin. hopefully user efforts could verify this!... the question of course remains regardless of the blue bill being good or not, can it be used even if original?

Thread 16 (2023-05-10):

Using plipbox with Pitstorm32 lite, Emu68 & Roadshow

tlgrooms, 2023-05-10:
I have recently set up my pistorm32 lite in my 1200 and installed os3.2, on the latest emu68 and the RTG picasso96 drivers.  I own Roadshow also and have tried installing the plipbox.device driver and Roadshow on it.  It installs OK and starts OK.  I have set a fixed ip and set up the dns servers and gateway, all configured properly but can't get it to work.  The debug shows it sets the ip address properly and netmask but I can't get out.  Tried pinging names and direct ips.  Not getting anywhere.  Tried pinging my router directly with it's ip and cannot ping it. I can ping localhost and my ip and it shows working ok, just can't get out.

Is there any kind of problem with using the plipbox with emu68 and the pistorm32 lite?  I have set up the hard drives and installed os 3.2 and everything else appears to be working fine.  Is there something I am missing?  I have used the plipbox on my 1200 before without a pistorm without any problems.  Thanks for any help.

craziazkowboi, 2023-05-26:
Check the issue https://github.com/cnvogelg/plipbox/issues/3

It may work for you too.  In my Amiga1000 with an 68030-TK2 accelerator I had the same symptoms as you until I :

1) Recapped my mainboard and power supply
2) Added a heatsink to the chip behind the ethernet interface (not the nano, its fine)
3) switched to using USB to provide power and not the Barrel connector.  Also using a USB power brick - 5v, max 2.5amps, not a USB port.

Worked flawlessly from there.  And just today I received my v3 Plipbox from Amiga68k.com, which runs even better - faster, cooler, and no heatsinks needed.

Good luck for your own journey!

powaking, 2023-05-31:
What worked for me was to set the NOBURST in envarc:sana2/plipbox.config file. This is on my A1200, Pistorm32 and MiamiDX/Genesis. Although with Genesis I had to set a static IP but MiamiDX worked with DHCP. No matter what I tried (heatsinks on the ethernet chip, can't use USB as its right up against my case) I could not get it to work without the NOBURST setting. May want to give that a try and see if that works for you.

tlgrooms, 2023-06-02:
NOBURST also worked for me.  Thanks guys for the info.

When I reboot the machine I have to power off the plipbox to get it to reset and work.  Is that normal?  Anyway to do it without restarting it every time as well?

powaking, 2023-06-02:
I sometimes would have to do that. My plipbox has a Nano on it with a reset switch. Sometimes that works but when it doesn't then doing a full power cycle is the obvious solution.

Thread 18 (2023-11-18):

Compatibility Issue : ENC28J60 from aliexpress

youenchene, 2023-11-18:
Hello,

Got some issue on making my DIY plipbox.

After hours of digging it looks like it's the Ethernet module I boughts from aliexpress : https://fr.aliexpress.com/item/1956963721.html

I checked both module are microchip version with a /SS at the end.

**Case 1 :**

Ethernet Nano module connect to the arduino to the amiga or not.

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

Looks like the software is frozen. Impossible to send a key command or go in command mode.

On amiga side, everything looks ok, except it doesn't work.

**Case 2 :**

Arduino nano connected with the mini version (tested with 3.3v from arduino and from external supply)

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

CS as SS pin.

Serail logs :

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

You can interact with the plipbox software, go in command mode etc ...

youenchene, 2023-11-18:
Just tested case 1 in à 5 version.

Same behavior but different logs :

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

geosone, 2023-12-22:
i have the same problem

ByteMavericks, 2024-01-31:
Same problem here as post #1.  Red board, has /SS at the end of the chip onboard.  Not sure if that's the issue or not but it hangs at the same place, just after pio init...  and then does not respond to anything.  This was from Amazon, I believe.

ByteMavericks, 2024-01-31:
Well, it's not a problem with Plipbox at all - there's an error on some shields.  Basically D12 is connected via a via to the ground of the voltage regulator, and it shouldn't be: it's the MISO line! https://arduino.stackexchange.com/questions/68144/nano-cant-get-reply-from-enc28j60-ethernet-shield

There's a video on youtube how to fix it.

youenchene, 2024-01-31:
Tx @ByteMavericks !

would be great if you remember the youtube link.

geosone, 2024-01-31:
i thonk its this video https://www.youtube.com/watch?v=o3N4AXD6fn8

ByteMavericks, 2024-01-31:
That's exactly it, thanks @geosone :) . Of course, I've soldered the thing to a PCB now so tonight's job is desoldering it... :)

geosone, 2024-01-31:
me too the comming weekend. or a week later depends on do i need a desoldering gun that i have to buy.

youenchene, 2024-02-04:
Ok got some progress on my side.

Behavior after having destroyed the miso/ground connection.

### 0.5

```
Welcome to plipbox 0.5 20131129
by lallafa (http://www.lallafa.de/blog)

fd: full duplex  00
fc: ETH flow ctl 01
fe: filter ETH   01
fp: filter PLIP  01

dd: dump dirs    00
de: dump ETH     00
di: dump IP      00
da: dump ARP     00
dp: dump proto   00
dl: dump plip    00

la: log all cmds 00

enc28j60: ERROR SETTING UP!!
```

After trying a connection  from the amiga: Error (3,1) trying to configure SANA-II Device.

### 0.6

```
Welcome to plipbox 0.6 20150117
by lallafa (http://www.lallafa.de/blog)

m: mac address   1A:11:AF:A0:47:11

fd: full duplex  00
fc: flow control 00

tl: packet len   05EA
tt: packet type  FFFD
ti: ip address   192.168.002.222
tp: udp port     1A90
tm: test mode    00

Press <return> to enter command mode or <?> for key help
000000.0581 [BRIDGE] on
000000.0624 pio: init: enc28j60: ok! mac=1A:11:AF:A0:47:11 flags=04 rev=00
000004.0178 FIRST INCOMING!
000004.0229 OFFLINE DROP: FFFC
000004.0375 OFFLINE DROP: FFFC
000004.0565 OFFLINE DROP: FFFC
000004.0621 OFFLINE DROP: FFFC
000004.0737 OFFLINE DROP: FFFC
000004.0825 OFFLINE DROP: FFFB
000004.0928 OFFLINE DROP: FFFC
000004.1017 OFFLINE DROP: FFFB
000004.1121 OFFLINE DROP: FFFC
000004.1210 OFFLINE DROP: FFFB
000004.1266 OFFLINE DROP: FFFC
000004.1323 OFFLINE DROP: FFFC
000004.1411 OFFLINE DROP: FFFB
...
000056.3935 OFFLINE DROP: FFFB
000056.3992 [MAGIC] online
000056.4077 FIRST TRANSFER!
```

Then impossible to interact to the terminal once I actviate Online on MiamiDX

Basically network is not working.

**Command p (before connexion)**

```
m: mac address   1A:11:AF:A0:47:11

fd: full duplex  00
fc: flow control 00

tl: packet len   05EA
tt: packet type  FFFD
ti: ip address   192.168.002.222
tp: udp port     1A90
tm: test mode    00
00 OK
```

**Weird behavior on ping :**

```
 ping 192.168.0.34                                                                                2 ↵ ──(Dim,fév04)─┘
PING 192.168.0.34 (192.168.0.34): 56 data bytes
Request timeout for icmp_seq 0
ping: sendto: No route to host
Request timeout for icmp_seq 1
ping: sendto: Host is down
Request timeout for icmp_seq 2
ping: sendto: Host is down
Request timeout for icmp_seq 3
```

(no ping on amiga side)

**dev_test -d plipbox.device**

On amiga side

```
[plipbox 0.6 (17.01.2025)
 (0,0)]
Waiting for incoming packets…
```

On Terminal side

```
000132.1136 [MAGIC] online
000132.1330 FIRST TRANSFER!
```

youenchene, 2024-02-04:
May be I have destroyed a bit too much (and link between D12 and MISO)

ByteMavericks, 2024-02-10:
I would say you've probably damaged the connection that is supposed to be there, but it's unreliable. The other question is where did you get your Arduino from...?

I gave up with repairing mine, and bought a new load of adapters from aliexpress. Have built one up and now about to test...

youenchene, 2024-02-11:
One official from europe and one cheap from ali.

I am stuck in the desoldering. (It's a pain in the a...)

So keep me updated with your new adapters.

ByteMavericks, 2024-04-09:
Well, with the new adaptors I'm still getting no joy. PIO_TEST just times out despite setting the IP address and port on the parameters and matching on pio_test...  and in bridge mode I keep seeing OFFLINE DROP 003C and 00E6.  Nothing on the Amiga, it fails to configure.

ByteMavericks, 2024-04-09:
I've also tried different Arduino Nano v3, including ones from arduino themselves.  Exactly the same.  I am suspecting the ethernet modules... again!

youenchene, 2024-04-18:
ok... can you share the references of the ethernet modules which gave no results.

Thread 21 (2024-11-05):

Arduino Nano V3 compatibility fix?

butterrsoft, 2024-11-05:
I'm having the same issue a i think lot of us are, in that the cheap Aliexpress Arduino Nano V3 boards will program ok but then not work properly when trying to configure or use them. I suspect it's the same problem going on in issue #18 as well. The fixed ENC28J60 ethernet shields don't help, and even without a shield connected the Nano 3.0 behaves the same way - seems to program and verify ok, but won't work properly under a Serial terminal or on the Amiga. (My Nano behaves very ,very slightly differently with different USB-C cables, as well. Might it be a power delivery issue?)

This is also recorded in Issue #14 by @salocinx. He mentions the new bootloader and the CH340 without external crystal [on the arduino forums](https://forum.arduino.cc/t/how-to-downgrade-arduino-nano-v3-to-old-bootloader/979848/5) - without success, it appears. @salocinx, did you find a solution?

Not to hassle you @cnvogelg but do you know if there is anything to be done?

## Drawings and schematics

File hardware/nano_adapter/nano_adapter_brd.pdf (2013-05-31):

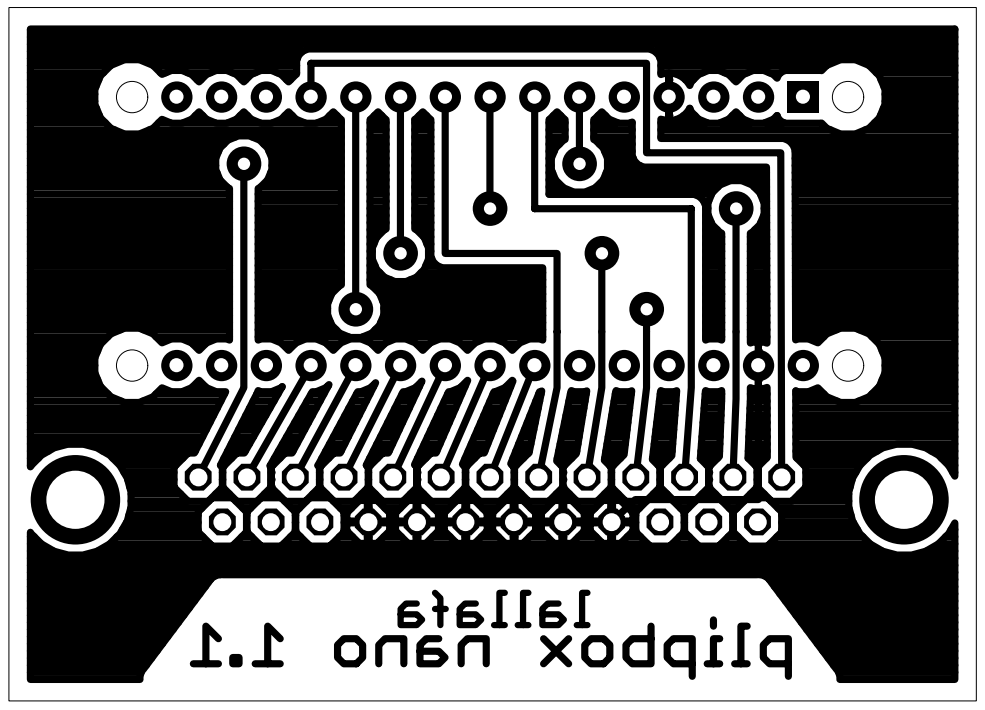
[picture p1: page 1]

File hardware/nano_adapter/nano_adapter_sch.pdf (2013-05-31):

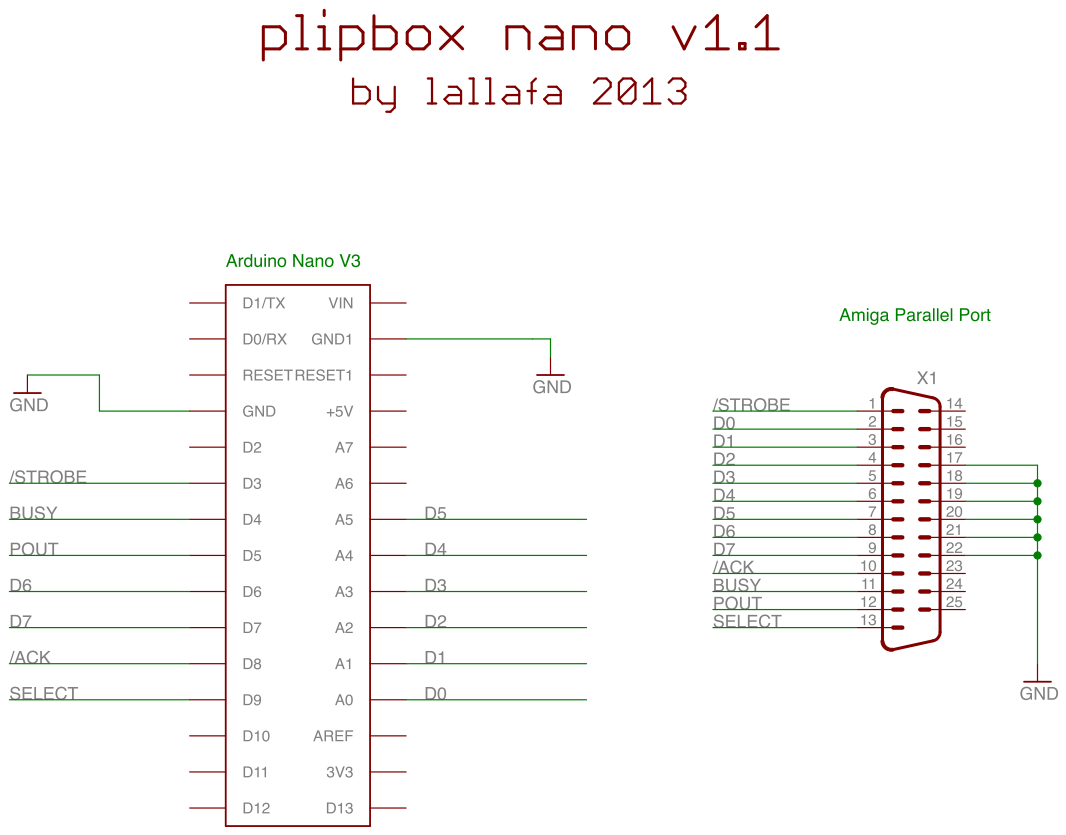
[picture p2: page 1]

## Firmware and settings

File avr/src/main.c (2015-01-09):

/*
 * main.c - main loop
 *
 * Written by
 *  Christian Vogelgsang <chris@vogelgsang.org>
 *
 * This file is part of plipbox.
 * See README for copyright notice.
 *
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
 */

#include <util/delay.h>

#include "global.h"
#include "board.h"
#include "uart.h"
#include "uartutil.h"
#include "timer.h"
#include "par_low.h"
#include "param.h"
#include "cmd.h"

#include "pb_test.h"
#include "pio_test.h"
#include "bridge_test.h"
#include "bridge.h"
#include "main.h"

u08 run_mode = RUN_MODE_BRIDGE;
u08 global_verbose = 0;

static void init_hw(void)
{
  // board init. e.g. switch off watchdog
  board_init();  
  // setup timer
  timer_init();
  // setup serial
  uart_init();
  // setup par
  par_low_init();
}

static void loop(void)
{
  init_hw();
  
  // send welcome
  uart_send_pstring(PSTR("\r\nWelcome to plipbox " VERSION " " BUILD_DATE "\r\n"));
  uart_send_pstring(PSTR("by lallafa (http://www.lallafa.de/blog)\r\n\r\n"));
  
  // param init
  param_init();  
  param_dump();
  uart_send_crlf();

  // help info
  uart_send_pstring(PSTR("Press <return> to enter command mode or <?> for key help\r\n"));

#ifdef DEBUG
  uart_send_free_stack();
#endif

  // select main loop depending on current run mode
  while(1) {
    u08 result = CMD_WORKER_IDLE;
    switch(run_mode) {
      case RUN_MODE_PB_TEST:
        result = pb_test_loop();
        break;
      case RUN_MODE_PIO_TEST:
        result = pio_test_loop();
        break;
      case RUN_MODE_BRIDGE_TEST:
        result = bridge_test_loop();
        break;
      case RUN_MODE_BRIDGE:
      default:
        result = bridge_loop();
        break;
    }
    // exit loop to perform reset
    if(result == CMD_WORKER_RESET) {
      break;
    }
  }

  // wait a bit
  uart_send_pstring(PSTR("resetting...\r\n"));
  _delay_ms(100);
}

int main(void)
{
  while(1) {
    loop();
  }
  return 0;
} 

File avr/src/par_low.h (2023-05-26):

/*
 * par_low.h - low_level routines to access amiga parallel port
 *
 * Written by
 *  Christian Vogelgsang <chris@vogelgsang.org>
 *
 * This file is part of plipbox.
 * See README for copyright notice.
 *
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
 */

#ifndef PAR_LOW_H
#define PAR_LOW_H

#include "global.h"

#include <avr/io.h>

#ifdef HAVE_arduino

/*
    Parallel Port Connection
                     Arduino        Nano
    DATA 0 ... 5     PC 0 ... 5     same      IN/OUT
    DATA 6 ... 7     PD 6 ... 7     same      IN/OUT
    
    /STROBE          PD 2           PD3       IN (INT0 / INT1)
    SELECT           PD 3           PB1       IN
    BUSY             PD 4           same      OUT
    POUT             PD 5           same      IN
    /ACK             PB 0           same      OUT
*/

// lower bits of data
#define PAR_DATA_LO_MASK        0x3f
#define PAR_DATA_LO_PORT        PORTC
#define PAR_DATA_LO_PIN         PINC
#define PAR_DATA_LO_DDR         DDRC    

// high bits of data
#define PAR_DATA_HI_MASK        0xc0
#define PAR_DATA_HI_PORT        PORTD
#define PAR_DATA_HI_PIN         PIND
#define PAR_DATA_HI_DDR         DDRD

#ifdef HAVE_nano
// /STROBE (IN) (INT1) (D3)
#define PAR_STROBE_BIT          3
#define PAR_STROBE_MASK         _BV(PAR_STROBE_BIT)
#define PAR_STROBE_PORT         PORTD
#define PAR_STROBE_PIN          PIND
#define PAR_STROBE_DDR          DDRD
#else
// /STROBE (IN) (INT0) (D2)
#define PAR_STROBE_BIT          2
#define PAR_STROBE_MASK         _BV(PAR_STROBE_BIT)
#define PAR_STROBE_PORT         PORTD
#define PAR_STROBE_PIN          PIND
#define PAR_STROBE_DDR          DDRD
#endif

#ifdef HAVE_nano
// SELECT (IN) (D9)
#define PAR_SELECT_BIT          1
#define PAR_SELECT_MASK         _BV(PAR_SELECT_BIT)
#define PAR_SELECT_PORT         PORTB
#define PAR_SELECT_PIN          PINB
#define PAR_SELECT_DDR          DDRB 
#else
// SELECT (IN) (D3)
#define PAR_SELECT_BIT          3
#define PAR_SELECT_MASK         _BV(PAR_SELECT_BIT)
#define PAR_SELECT_PORT         PORTD
#define PAR_SELECT_PIN          PIND
#define PAR_SELECT_DDR          DDRD 
#endif

// BUSY (OUT) (D4)
#define PAR_BUSY_BIT            4
#define PAR_BUSY_MASK           _BV(PAR_BUSY_BIT)
#define PAR_BUSY_PORT           PORTD
#define PAR_BUSY_PIN            PIND
#define PAR_BUSY_DDR            DDRD 

// POUT (IN) (D5)
#define PAR_POUT_BIT            5
#define PAR_POUT_MASK           _BV(PAR_POUT_BIT)
#define PAR_POUT_PORT           PORTD
#define PAR_POUT_PIN            PIND
#define PAR_POUT_DDR            DDRD 

// /ACK (OUT) (D8)
#define PAR_ACK_BIT             0
#define PAR_ACK_MASK            _BV(PAR_ACK_BIT)
#define PAR_ACK_PORT            PORTB
#define PAR_ACK_PIN             PINB
#define PAR_ACK_DDR             DDRB

#else
#ifdef HAVE_avrnetio
    
/*
    Parallel Port Connection (AVR Net IO board)
                      AVR
    DATA 0 ... 7     PC 0 ... 7     IN/OUT
    
    /STROBE          PD 2           IN (INT0)
    SELECT           PA 3           IN
    POUT             PA 2           IN
    BUSY             PA 1           OUT
    /ACK             PA 0           OUT
*/

// lower bits of data
#define PAR_DATA_PORT           PORTC
#define PAR_DATA_PIN            PINC
#define PAR_DATA_DDR            DDRC    

// /STROBE (IN) (INT0)
#define PAR_STROBE_BIT          2
#define PAR_STROBE_MASK         _BV(PAR_STROBE_BIT)
#define PAR_STROBE_PORT         PORTD
#define PAR_STROBE_PIN          PIND
#define PAR_STROBE_DDR          DDRD

// SELECT (IN) (INT1)
#define PAR_SELECT_BIT          3
#define PAR_SELECT_MASK         _BV(PAR_SELECT_BIT)
#define PAR_SELECT_PORT         PORTA
#define PAR_SELECT_PIN          PINA
#define PAR_SELECT_DDR          DDRA 

// POUT (IN)
#define PAR_POUT_BIT            2
#define PAR_POUT_MASK           _BV(PAR_POUT_BIT)
#define PAR_POUT_PORT           PORTA
#define PAR_POUT_PIN            PINA
#define PAR_POUT_DDR            DDRA 

// BUSY (OUT)
#define PAR_BUSY_BIT            1
#define PAR_BUSY_MASK           _BV(PAR_BUSY_BIT)
#define PAR_BUSY_PORT           PORTA
#define PAR_BUSY_PIN            PINA
#define PAR_BUSY_DDR            DDRA 

// /ACK (OUT)
#define PAR_ACK_BIT             0
#define PAR_ACK_MASK            _BV(PAR_ACK_BIT)
#define PAR_ACK_PORT            PORTA
#define PAR_ACK_PIN             PINA
#define PAR_ACK_DDR             DDRA
                        
#else
#error "Unknwon Board"        
#endif
#endif

// ----- Input Buffer Handling -----

#define PAR_IN_BUF_BITS     4
#define PAR_IN_BUF_SIZE     (1 << PAR_IN_BUF_BITS)
#define PAR_IN_BUF_MASK     (PAR_IN_BUF_SIZE - 1)

// ----- Functions -----

extern void par_low_init(void);

// ----- Data Bus -----

extern void par_low_data_set_output(void);
extern void par_low_data_set_input(void);

#ifdef HAVE_arduino
static inline void par_low_data_out(u08 d)
{
  PAR_DATA_LO_PORT = (d & PAR_DATA_LO_MASK) | (PAR_DATA_LO_PIN & ~PAR_DATA_LO_MASK);
  PAR_DATA_HI_PORT = (d & PAR_DATA_HI_MASK) | (PAR_DATA_HI_PIN & ~PAR_DATA_HI_MASK);
}

static inline u08 par_low_data_in(void)
{
  u08 d1 = PAR_DATA_LO_PIN & PAR_DATA_LO_MASK;
  u08 d2 = PAR_DATA_HI_PIN & PAR_DATA_HI_MASK;
  return d1 | d2;
}
#else
#ifdef HAVE_avrnetio
static inline void par_low_data_out(u08 d)
{
  PAR_DATA_PORT = d;
}

static inline u08 par_low_data_in(void)
{
  return PAR_DATA_PIN;
}
#endif
#endif

// ----- Signals -----

// /ACK (OUT)

static inline void par_low_set_ack_lo(void)
{
  PAR_ACK_PORT &= ~PAR_ACK_MASK;
}

static inline void par_low_set_ack_hi(void)
{
  PAR_ACK_PORT |= PAR_ACK_MASK;
}

extern void par_low_pulse_ack(u08 delay);

// BUSY (OUT)

static inline void par_low_set_busy_lo(void)
{
  PAR_BUSY_PORT &= ~PAR_BUSY_MASK;
}

static inline void par_low_set_busy_hi(void)
{
  PAR_BUSY_PORT |= PAR_BUSY_MASK;
}

// STROBE (IN)

static inline u08 par_low_get_strobe(void)
{
  return (PAR_STROBE_PIN & PAR_STROBE_MASK) == PAR_STROBE_MASK;
}

// SELECT (IN)

static inline u08 par_low_get_select(void)
{
  return (PAR_SELECT_PIN & PAR_SELECT_MASK) == PAR_SELECT_MASK;
}

// POUT (IN)

static inline u08 par_low_get_pout(void)
{
  return (PAR_POUT_PIN & PAR_POUT_MASK) == PAR_POUT_MASK;
}

#endif

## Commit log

2011-07-19 initial board bringup
2011-07-21 device now pings via plip
2011-07-24 slip rx works now
    [main.c]
2011-08-14 added magplip device builds and patch
2011-08-15 added slip local ping
    [main.c]
2011-08-18 added -H to slattach to avoid Arduino resets on disconnect
2011-08-28 added error led handling
    [main.c]
2012-06-01 refactored SPI
2012-06-03 updated magplip driver to 38.1b
2012-07-22 fixed bug blocking eth after dhcp
    [eth_rx.c]
2012-07-22 fixed plip tx regression
    [eth_rx.c]
2012-07-22 fixed plipbox project name
    [eth_rx.c]
2012-08-26 added avrnetio board
2013-04-22 de-tabbed amiga src
2013-04-27 fixed max eth frame size
    [dump.c, enc28j60.c, eth_rx.c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]
2013-05-04 adapted avr code to new plip frames
2013-05-04 improved packet filtering
2013-05-12 handle config addr correctly
    [magplip.h]
2013-05-21 allow to toggle packet filtering
2013-05-31 added nano adapter board
    [nano_adapter.brd, nano_adapter.sch]
2013-10-09 own board dir
2013-10-11 lots of avr code fixes
    [enc28j60.c, pb_io.c]
2013-10-30 push mac from driver to firmware
2013-11-07 added flow control
2013-11-29 added full duplex param and reset device command
    [main.c, param.c]
2014-04-26 pass device version via make
2014-04-28 introduced device specific sub dir
2014-04-28 fixed device header
2014-06-07 factored out eth frame
2014-06-09 use threading for readers
2014-06-19 improved threading
2014-09-27 use current date for device
2014-09-27 added driver detection
2014-10-12 ami: added internal packet loop back in driver
2014-10-12 avr: test mode fixes
    [main.c]
2014-10-24 avr: show device usage in 'elf' target
2014-11-28 avr: introduced generic pio devices
2014-11-28 avr: added missing files
    [pio.c]
2014-11-29 avr: inlined spi
2014-12-14 ami: fixed device name
2015-01-09 avr: set correct pio init flags
    [bridge.c, pio.c, pio_util.c]
2015-01-09 avr: fixed reset. fixed magic send. added flow control.
    [bridge.c, enc28j60.c, main.c]
2015-01-09 avr: corrected timer reset
2015-01-11 doc: added plipbox.device options
2023-05-27 amiga: ported to Roadshow and use current devenv

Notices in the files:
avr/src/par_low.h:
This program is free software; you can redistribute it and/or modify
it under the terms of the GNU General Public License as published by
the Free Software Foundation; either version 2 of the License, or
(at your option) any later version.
